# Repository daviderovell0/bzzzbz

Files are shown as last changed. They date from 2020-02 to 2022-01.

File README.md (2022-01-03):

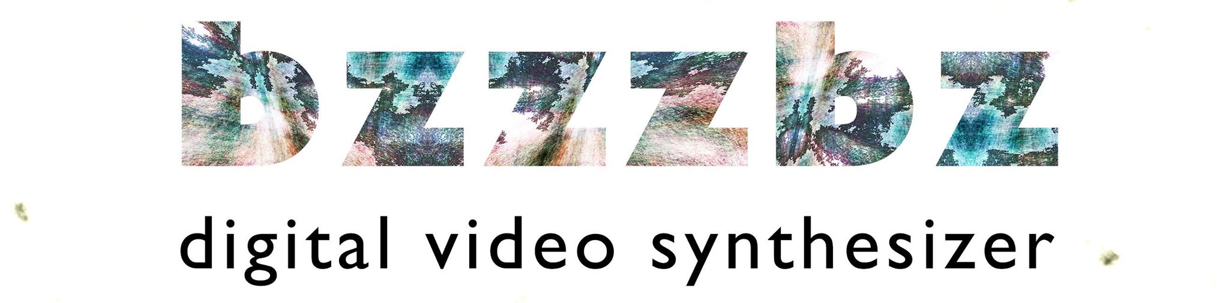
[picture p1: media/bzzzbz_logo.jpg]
bzzzbz Logo

**bzzzbz** is a video synthesizer that dynamically reacts to an audio input to create images and visuals that can be manipulated for integrated audio-visual performances.  <br>
This product is meant to be a simpler and cheaper alternative to commercial analog video synthesizers, still providing a flexible interface to enhance musical expression.

If you are a musician, a visual artist or are curious about the mesmerizing videos on the wall of your local techno club, build and use  **bzzzbz** to experiment and play with audio-reactive visuals! Among its main features, this open-source video synth gives you the live control of video parameters and the possibility of creating your own mappings and patterns for immersive audiovisual performances.
## Documentation
Visit our [wiki](https://github.com/daviderovell0/bzzzbz/wiki) for the full documentation. 
## Contributions
- Davide Rovelli (daviderovell0)
- Peter Nagy (deetrone)
- Marcell Illyes (marcellillyes)

This project was born at the University of Glasgow, School of Engineering. Credits to Dr.Bernd Porr, Dr. Nicholas Bailey and their Real Time Embedded Programming course.

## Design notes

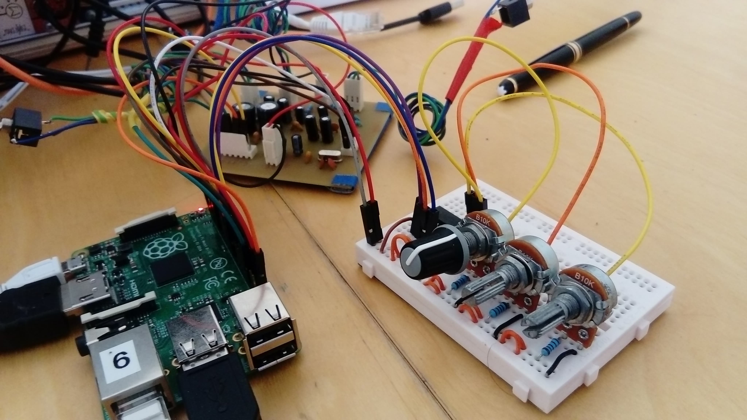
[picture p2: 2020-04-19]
media/hardware_prototype_full.jpg

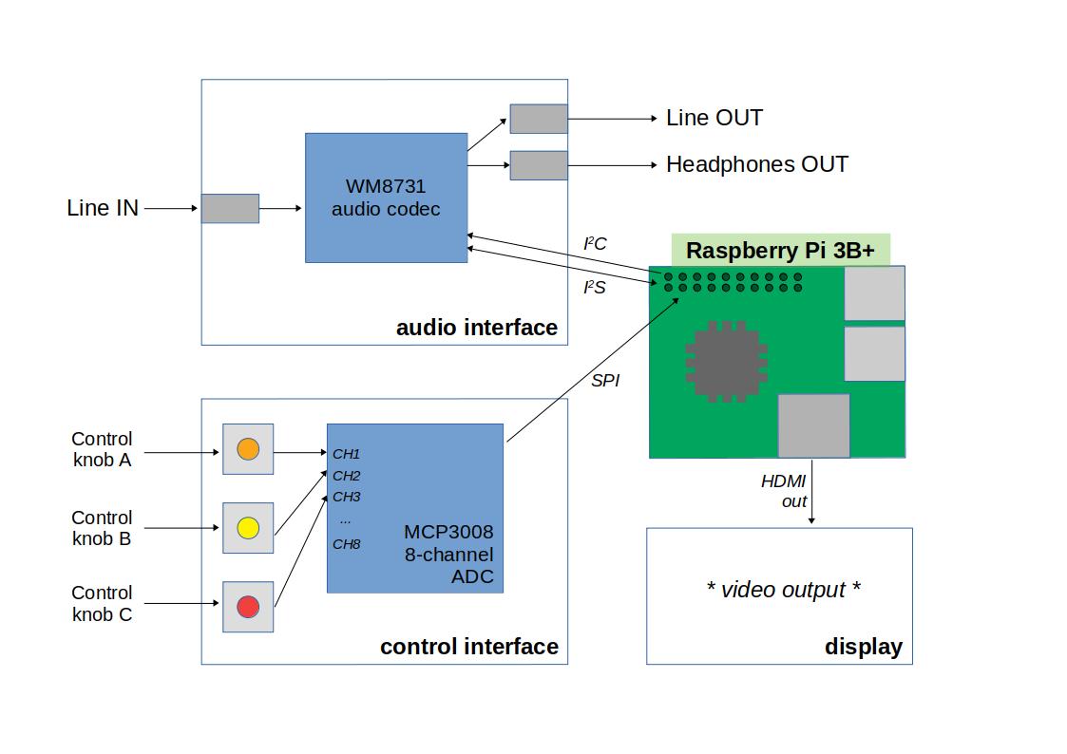
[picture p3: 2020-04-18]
media/hardware_diagram.jpg

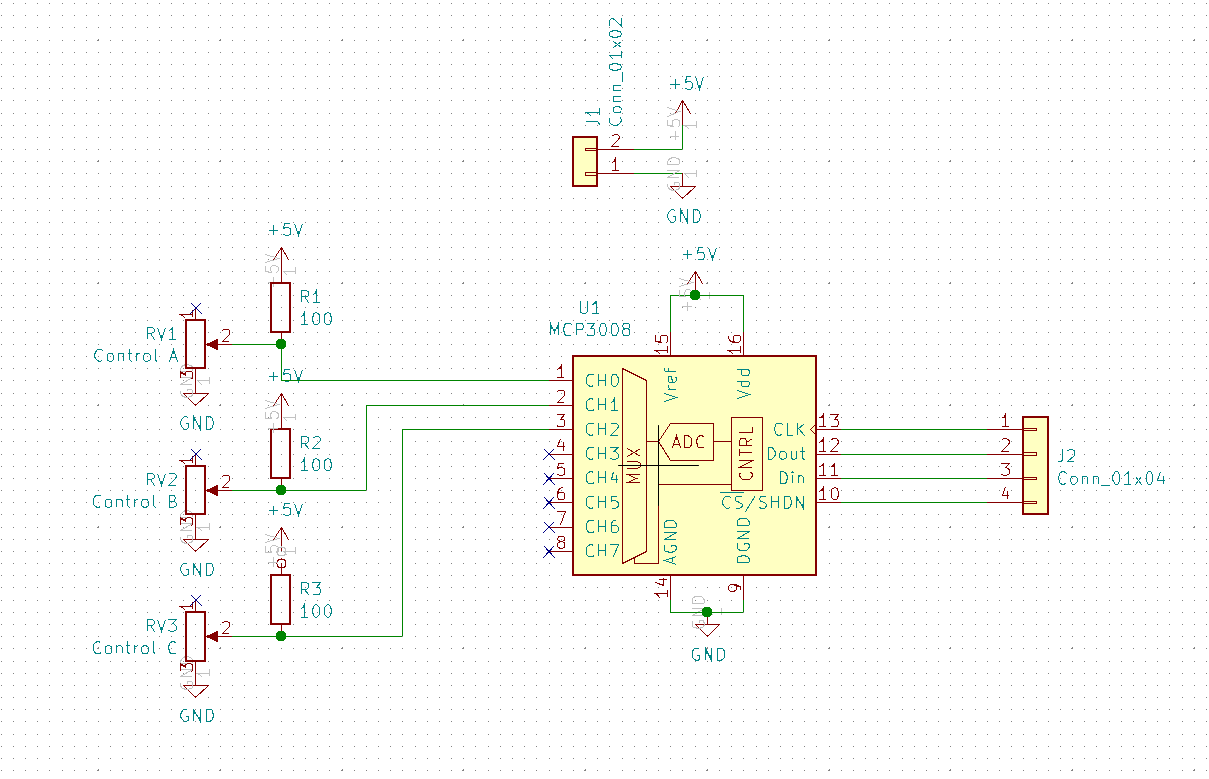
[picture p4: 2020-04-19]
media/mcp3008_breakout_schematic.png

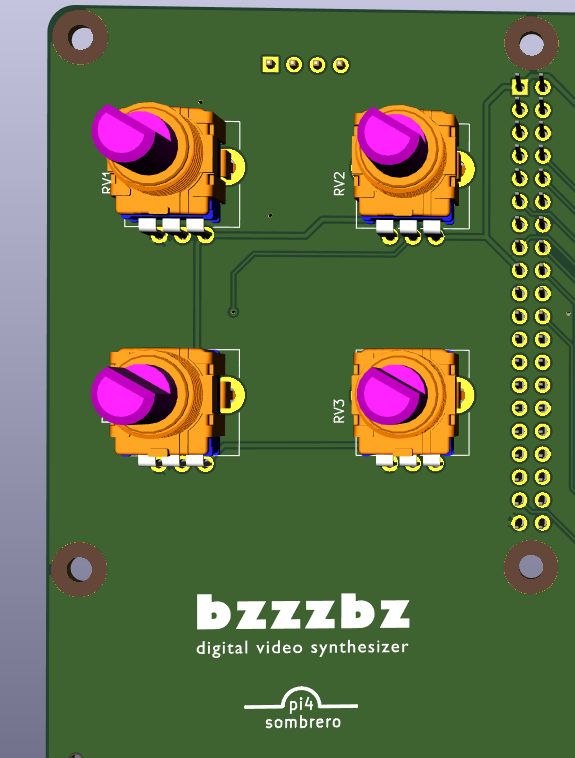
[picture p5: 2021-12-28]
hardware/3dmodels/pots_view.png

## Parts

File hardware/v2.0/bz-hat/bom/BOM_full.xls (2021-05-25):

BZZZBZ
References | Value | Mouser No / JLCPCB | Mfr. No | Manufacturer | Description | Order Qty. | Price (EUR) | Ext.: (EUR)
J1,J2,J3 | LineIN,LineOUT,Headphones | 490-SJ1-3533NG | SJ1-3533NG | CUI Devices | Phone Connectors Audio Jacks | 3 | 0.787 | 2.361
J4 |  | 485-1992 | 1992 | Adafruit | Adafruit Accessories GPIO Header for RaspberryPi A+/B+/Pi 2/Pi 3 - Tall 2x20 Female Header | 1 | 2.500 | 2.5
RV1, RV2, RV3, RV4 |  | 688-RK09L114001T | RK09L114001T | Alps Alpine | Potentiometers Flat 20mm 10k | 4 | 1.480 | 5.92
J5, J6 |  | 437-3508013100006101 | 350-80-131-00-006101 | Preci-dip | Headers & Wire Housings 31x1 female (only 20x1 + 4x1 needed) | 1 | 2.410 | 2.41
SW1, SW3, SW4, SW5 | BTN_1, BTN_2, BTN_3, BTN_f | 612-TL1100-6JBLK | TL1100F160Q6JBLK | E-Switch | Tactile Switches 50mA 12VDC SPST 12x12mm Blk Cap | 4 | 0.636 | 2.544
SW2 | BTN_big | 612-PB300STQ | PB300STQ | E-Switch | Pushbutton Switches Long Travel Pushbutton Switch 30mA 28VDC SPST 490+/- 150gf -40 C to 95 C | 1 | 1.410 | 1.41
U1, U3 | MCP3004 | 579-MCP3004-I/SL | MCP3004-I/SL | Microchip | Analog to Digital Converters - ADC 10-bit SPI 4 Chl IND TEMP, SOIC14 | 2 | 1.850 | 3.7
J6 |  | 437-3508013100006101 | 350-80-131-00-006101 | Preci-dip | Header for display: 2.54mm pitch, 20x1, male | 1 | 2.400 | 2.4
J6 | NHD-2.23-12832UCB3 | 763-NHD22312832UCW3 | NHD-2.23-12832UCW3 | Newhaven Display | OLED Displays & Accessories 2.23 Graphic OLED White | 1 | 23.430 | 23.43
U2 | WM8731 | / | WM8731SEDS/V | Cirrus Logic | Audio analog to digital converter - 24 bit headphone + line in + lineout | 1 | 3.62 | 3.62
C3, C4, C7, C8, C18, C20 | 1uF | JLCPCB parts | TAJA105K035RNJ | AVX | Tantalum capacitor SMT | 6 | 0.13 | 0.78
C9, C10, C11, C15, C19 | 10uF | JLCPCB parts | TAJA106K016RNJ | AVX | Tantalum capacitor SMT | 5 | 0.17 | 0.85
C5, C6 | 220uF | JLCPCB parts | VES221M1CTR-0607 | LELON | Almuninum capacitor SMT | 2 | 0.04 | 0.08
C1, C2 | 220pF | JLCPCB parts | CL10B221KB8NNNC | Samsung Electro-Mechanics | Ceramic capacitor SMT | 2 | 0.006 | 0.012
C13 | 0.1uF | JLCPCB parts | CL31B104KBCNNNC | Samsung Electro-Mechanics | Ceramic capacitor SMT | 1 | 0.02 | 0.02
C12, C14, C16, C17 | 0.1uF | JLCPCB parts | CC0603KRX7R9BB104 | Yageo | Ceramic capacitor SMT | 4 | 0.006 | 0.024
R3, R4 | 100 ohms | JLCPCB parts | 0805W8F1000T5E | Uniroyal Elec | Resistor SMT | 2 | 0.003 | 0.006
R7, R8, R9, R10 | 47k | JLCPCB parts | 0805W8F4702T5E | Uniroyal Elec | Resistor SMT | 4 | 0.004 | 0.016
R1, R2, R5, R6 | 5.6k | JLCPCB parts | 0805W8F5601T5E | Uniroyal Elec | Resistor SMT | 4 | 0.004 | 0.016
J4 | Raspberry_Pi_4 | / | / | Adafruit | 2 GB | 1 | 40 | 40
- | spacers for pi | 534-24426 | 24426 | Keystone Electronics | Spacers, 2.5x18, female (2x16 would be better) | 6 | 0.62 | 3.72
- | spacers for display (optional) | ? | ? | ? | Spacers, 2.5x10, female | 4 | 0.62 | 2.48
 |  |  |  |  |  |  | Total | 98.299

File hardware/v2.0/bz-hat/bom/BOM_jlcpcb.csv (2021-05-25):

Comment | Designator | Footprint | LCSC
220pF | C1,C2 | Capacitor_SMD:C_0603_1608Metric | C1603
0.1uF | C13 | Capacitor_SMD:C_1206_3216Metric | C24497
10uF | C9,C10,C11,C15,C19 | Capacitor_Tantalum_SMD:CP_EIA-3216-18_Kemet-A | C7171
0.1uF | C12,C14,C16,C17 | Capacitor_SMD:C_0603_1608Metric | C14663
220uF | C5,C6 | Capacitor_SMD:CP_Elec_6.3x7.7 | C127327
1uF | C3,C4,C7,C8,C18,C20 | Capacitor_Tantalum_SMD:CP_EIA-3216-18_Kemet-A | C7176
LineIN | J1 | custom:Jack_3.5mm_CUI_SJ1-3533NG_Horizontal
LineOUT | J2 | custom:Jack_3.5mm_CUI_SJ1-3533NG_Horizontal
Headphones | J3 | custom:Jack_3.5mm_CUI_SJ1-3533NG_Horizontal
Raspberry_Pi_4 | J4 | custom:PinHeader_2x20_P2.54mm_Vertical_RaspberryPI_HAT
CVs+CLK_connector | J5 | Connector_PinHeader_2.54mm:PinHeader_1x04_P2.54mm_Vertical
NHD-2.23-12832UCB3 | J6 | custom:Display_NHD-2.23-12832
5.6k | R1,R2,R5,R6 | Resistor_SMD:R_0805_2012Metric | C4382
100 | R3,R4 | Resistor_SMD:R_0805_2012Metric | C17408
47k | R7,R8,R9,R10 | Resistor_SMD:R_0805_2012Metric | C17713
10k | RV1,RV2,RV3,RV4 | Potentiometer_THT:Potentiometer_Alps_RK09L_Single_Vertical
BTN_f | SW1 | custom:SW_PUSH-12mm+3d
BTN_big | SW2 | custom:SW_PUSH_e-switch_PB300_SPST_12x12
BTN_1 | SW3 | custom:SW_PUSH-12mm+3d
BTN_2 | SW4 | custom:SW_PUSH-12mm+3d
BTN_3 | SW5 | custom:SW_PUSH-12mm+3d
MCP3004 | U1,U3 | Package_SO:SOIC-14_3.9x8.7mm_P1.27mm | C512186
WM8731 | U2 | custom:SSOP28-0.65-10.2X5.2MM | C323837

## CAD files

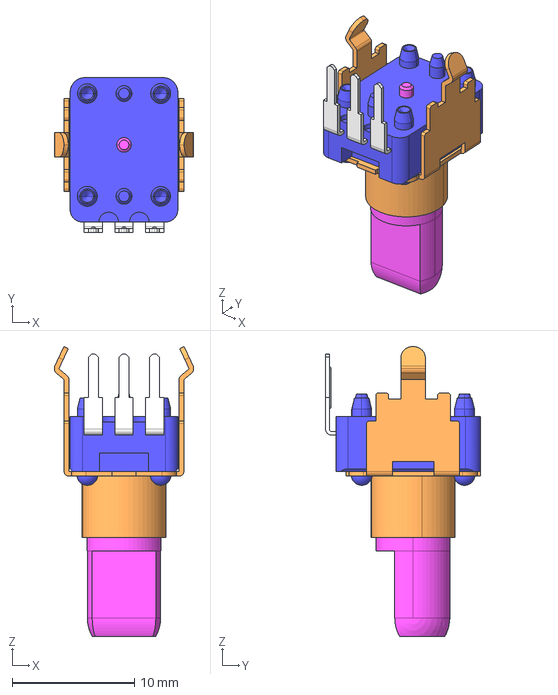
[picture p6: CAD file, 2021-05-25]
hardware/3dmodels/rk09d1130c3w.stp
11.4 x 12.7 x 23.7 mm

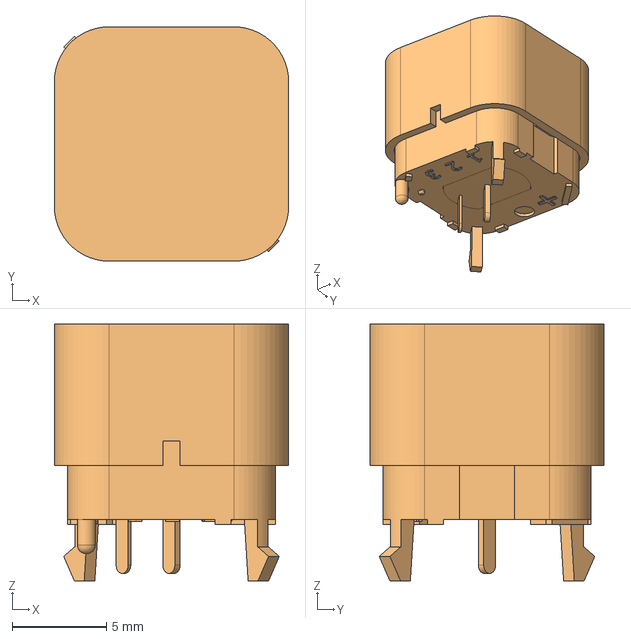
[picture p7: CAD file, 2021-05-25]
hardware/3dmodels/PB300STQ--3DModel-STEP-1.STEP
12.4 x 12.4 x 13.6 mm

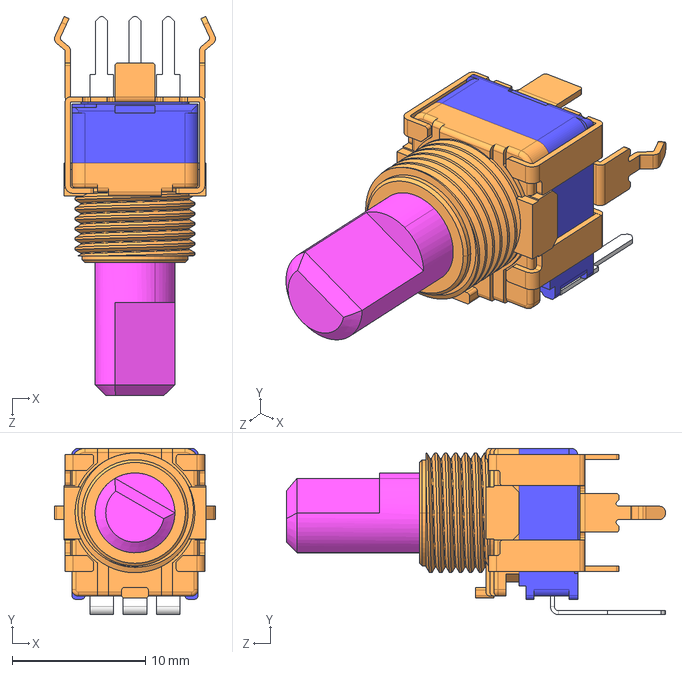
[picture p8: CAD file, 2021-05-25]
hardware/3dmodels/RK09L1140A5P.STEP
12.1 x 12.5 x 28.5 mm

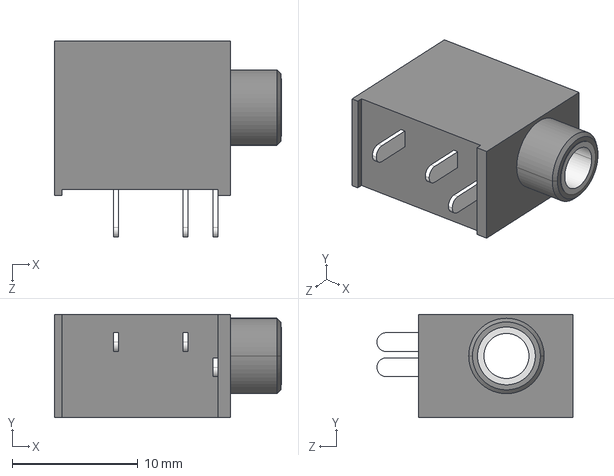
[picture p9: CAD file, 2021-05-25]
hardware/3dmodels/CUI_DEVICES_SJ1-3533NG.step
18.1 x 8.20 x 15.6 mm

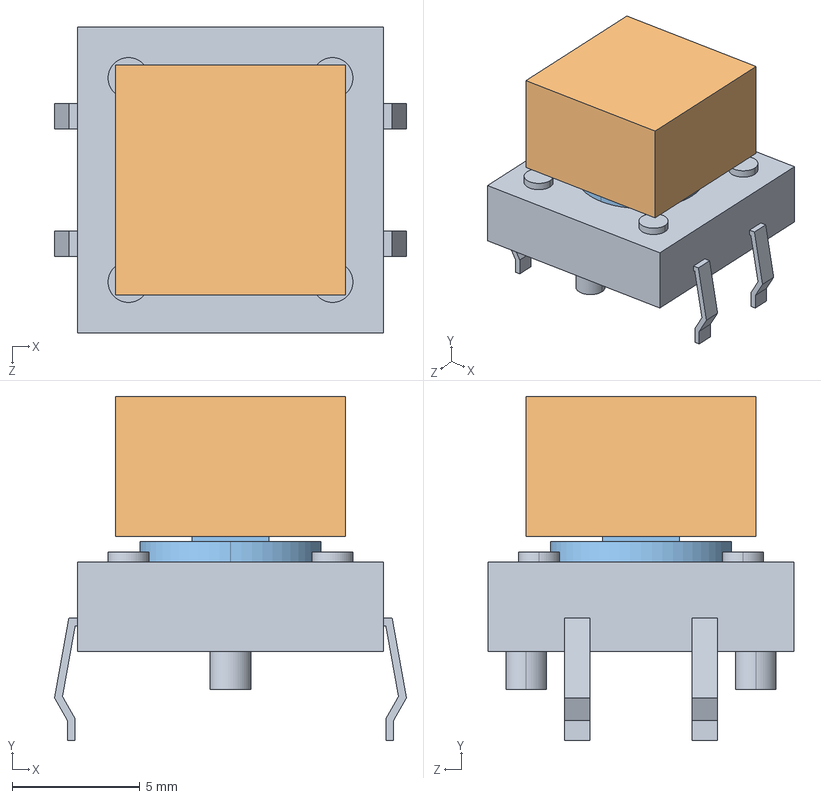
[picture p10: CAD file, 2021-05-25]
hardware/3dmodels/B3F-4050--3DModel-STEP-273799.STEP
13.8 x 13.5 x 12.0 mm
B3F_4050_BASE
B32_1200
B3F_4050_BUTTON

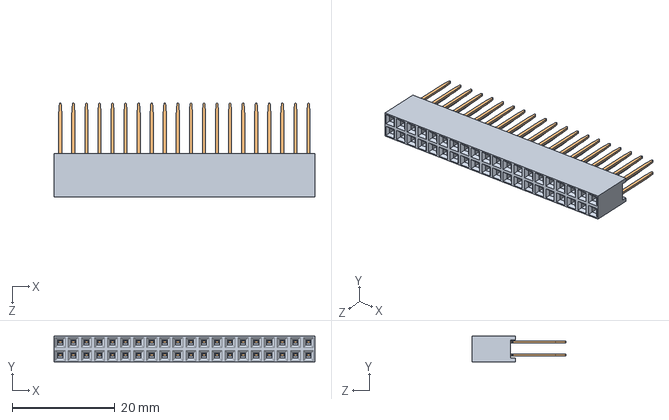
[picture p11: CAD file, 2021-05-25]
hardware/3dmodels/960240-6202-AR.STEP
50.8 x 5.00 x 18.3 mm
960240-6202-AR Body
960240-6202-AR Pin x 40

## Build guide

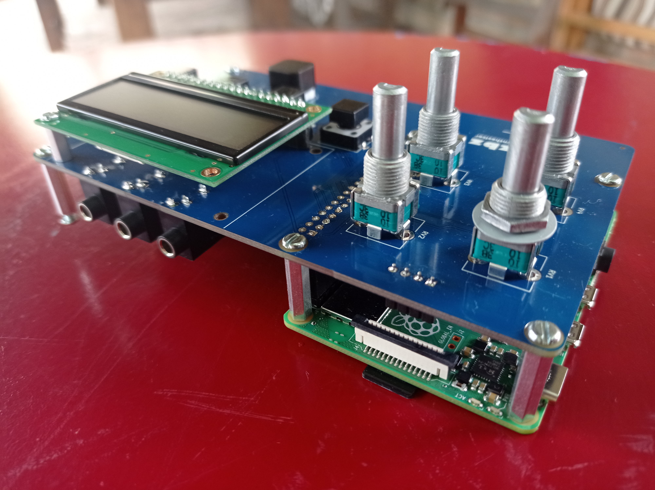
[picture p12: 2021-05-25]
media/board_v2_assembled_back.jpg

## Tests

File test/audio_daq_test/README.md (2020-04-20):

## Audio acquisition test

This folder contains a simple program that prints the samples coming from an audio port
of your device:
- For bzzzbz this would be the lineIN left channel of the stereo jack.
- For a laptop this is likely to be your build-in microphone.

It can be used to understand how the audio acquisition and processing works and also to 
test if the device receives audio data. Run:
```
cmake .
make
./audioin.o
```
If you see the samples varying accordingly to the input the audio is working.

### Plotting audio data
The *plot* folder contains a jupyter notebook that can be used to visualise audio data in the 
*samples* folder. The samples were recorded from **bzzzbz** line input. Files starting with *fft*
represent the frequency equivalent of the raw samples.

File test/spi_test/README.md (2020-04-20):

## SPI acquisition test

This folder contains a simple program that prints the samples coming from the control knobs
of **bzzzbz**.

It can be used to understand how the SPI clients manages acquisition and processing works and also to 
test if the device receives SPI data. Run:
```
cmake .
make
./spi_test.o
```
If you see the samples varying accordingly to the input the audio is working.

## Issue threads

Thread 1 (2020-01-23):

Sound processing design

daviderovell0, 2020-01-23:
We need to design specifications for the audio processing of bzzzbz video synth.

Currently ADC chip with jack input seems the most reasonable option.

deetrone, 2020-01-23:
E-mail Dr Porr to see if we can use external sound cards (hats)
Research available hats (important 192kHz, price, in/out?)

deetrone, 2020-01-24:
OG I2S specification:
https://web.archive.org/web/20080706121949/http://www.nxp.com/acrobat_download/various/I2SBUS.pdf

Pi as an oscilloscope (Kernel building stuff):
https://digibird1.wordpress.com/raspberry-pi-as-an-oscilloscope-10-msps/

Sticky thread on RPi forum re: I2S:
https://www.raspberrypi.org/forums/viewtopic.php?f=44&t=8496&start=575#p604231

deetrone, 2020-01-25:
I2S GPIO connections to TI PCM1808 ADC:

BCK/SCK - PCM-CLK-18 - pin8 on ADC (BCK)

WS/LRCLK/FS - PCM-FS 19 -  pin7 on ADC (LRCK)

SDIN - PCMDIN 20 - pin9 on ADC (DOUT)

+ clock, SCKI on ADC which is the "fast clock"

Closed 2020-04-02.

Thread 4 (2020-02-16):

Control surface / sensors design

daviderovell0, 2020-02-16:
We need to come up with a design for an expressive surface to control the video "synthesis" parameters.
We need to:
- choose the functions / actions we want to have
- choose sensors accordingly
- prototype them on breadboard
- PCB and surface/box design
- Assemble them together

Closed 2020-02-26.

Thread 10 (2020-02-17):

Breakout PCB

daviderovell0, 2020-02-17:
( #1 )
Check [datasheet](https://statics.cirrus.com/pubs/proDatasheet/WM8731_v4.9.pdf)
Check ONDA driver and make breakout

daviderovell0, 2020-03-04:
PCB submitted and manufactured, KiCAD files can be found in the *repo/hardware* folder

Closed 2020-03-04.

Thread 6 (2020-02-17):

Capabilities of OpenGL in the RaspberryPi

daviderovell0, 2020-02-17:
(#2)

How much processing power do we need for certain HQ graphics (such as fractals)?
Can the RaspberryPI support them?

Shall we consider generating video on a laptop and make the RaspberryPi send data only?

daviderovell0, 2020-02-19:
OpenGL ES (embedded system) 2.x

Closed 2020-02-26.

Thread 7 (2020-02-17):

Sensor types and prices

daviderovell0, 2020-02-17:
(#4)

Choose the expressive sensors, choose the ADCs (they MUST have already a kernel driver for raspbian).
Make sure that we have enough GPIO to interface with the ADCs and buttons.
Ensure we are under budget.

Closed 2020-02-19.

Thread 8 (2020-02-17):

Potentiometer GPIO sample program

daviderovell0, 2020-02-17:
( #4 )

Write a sample program that reads the input from the ADC connected to the potentiometer to start control off and have a reference for future work.

daviderovell0, 2020-02-17:
We have to use a third party library such as wiringPi or BCM2835

daviderovell0, 2020-04-02:
Implemented in Pull request: #29

Closed 2020-04-02.

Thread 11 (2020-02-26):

OpenGL video generation

daviderovell0, 2020-02-26:
Now that openGL is installed and running we need to get familiar with OpenGL functions and workflow in order to manipulate videos

daviderovell0, 2020-02-26:
- Broad OpenGL overview of main features
- Make a simple video prototype

daviderovell0, 2020-03-04:
This issue was migrated to #13 with more specuifications.

Closed 2020-03-04.

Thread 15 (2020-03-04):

Audio data stream

daviderovell0, 2020-03-04:
Get the audio data from the audio codec (WM8731).

plan:

- Solder PCB
- use ALSA or JACK to set the codec with the relevant options
- Capture the data in a cpp program

daviderovell0, 2020-03-28:
PR #27 plots audio data stream from the microphone of an Ubuntu laptop.

We have to replicate the process on the pi, although it might be impossible because of hardware faults in the soundcard.

daviderovell0, 2020-04-02:
Process successfully replicated on the PI, the samples were captured and saved on file at 48KHz. The current breakout board presents some issues on startup (the chip cannot be registered) and playback. However incoming audio can still be captured. Plots confirmed the validity of the audio data

Closed 2020-04-02.

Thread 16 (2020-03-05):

Box design and manufacture

daviderovell0, 2020-03-05:
Ideally we want to have a box or a sort of enclosure for controls input and outputs.

Design can be done in CAD (Solidworks)
Manufacture through 3D printing or laser cutting (?).

daviderovell0, 2020-03-23:
Manufacture suspended due to current COVID containment measures.

daviderovell0, 2020-09-01:
We back

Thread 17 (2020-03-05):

Final PCB design and mounting

daviderovell0, 2020-03-05:
PCB with control, audio input outputs and RasperryPi.
Steps:

- Final components design from prototype
- Order SMD components
- PCB design
- Assemble and test

daviderovell0, 2020-03-23:
Task currently suspended due to current COVID containment measures.

Closed 2020-09-01.

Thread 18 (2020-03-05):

Control surface data input

daviderovell0, 2020-03-05:
Further develop the simple potentiometer sample program (#8) to have an array of at least 4 potentiometers with data being read simultaneously (real time) from all 4.

Since the pots ADC uses SPI, the main idea is to write a loop that keeps switching SPI slave and reading each input in turn, fast enough to appear simultaneous. We might need to use /dev direct access programming instead of /sys library such as WiringPI to achieve higher speed.

daviderovell0, 2020-04-02:
Implemented in #29

Closed 2020-04-02.

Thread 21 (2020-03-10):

Slow response on the pi

daviderovell0, 2020-03-10:
Even using shaders (running on the pi GPU), a simple video shows some lags on the pi. The larger the window the more visible the lag.

daviderovell0, 2020-03-17:
Solved by installing OpenGL driver

Closed 2020-03-17.

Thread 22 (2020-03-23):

Headphone out unwanted high-pass filtered signal

daviderovell0, 2020-03-23:
The audio chip appears to be successfully bypassing the signal. The output is stable on the line out jack but not in the headphones out where the audio seems to miss the bass frequencies.

We need to figure out where this happens and fix it: it might be a circuit issue of the breakout board or a driver configuration.

daviderovell0, 2020-04-02:
It now appears to be on the LINEOUT instead

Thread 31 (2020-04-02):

RELEASE v1.0

daviderovell0, 2020-04-02:
Now that we have all the different sections working separately we need to put everything together in a main program. The most relevant points are:
- Mapping
- Thread sync
- Real time execution.

I suggest to do this in 2 separate merging: **video<->controls** and **audio<->FFT**. We can then proceed to merge the 2 into a single program and implement the mapping.
This will give us our first working prototype!

daviderovell0, 2020-04-19:
Code and examples up and working, need to refactor, link information to documentation and tidy up for the final release.

Closed 2020-04-20.

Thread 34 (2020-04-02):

Meaningful mapping

daviderovell0, 2020-04-02:
We need to find a way to meaningfully map audio and controls to video. For example a complex track with different instruments might map different frequencies to different video properties (i.e. object colors, size). However, this mapping might not make sense for a sine oscillator sweep for example, since the same "sound changing" would change different video properties.

We might be able to solve that with different types of mapping, giving the user the possibility to change according to its sound

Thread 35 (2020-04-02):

Control + video mapping

daviderovell0, 2020-04-02:
Refer to #31. Use the SPI potentiometer thread to update some test parameters in the video generation.
Test on laptop, then on PI.

daviderovell0, 2020-04-15:
Implemented in release_1.0 branch. Waiting for pull request to close

Closed 2020-04-18.

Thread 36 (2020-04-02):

Audio + FFT

daviderovell0, 2020-04-02:
Use jack thread to fill a buffer with incoming audio @ 48Khz, trigger an interrupt for the FFT processing.
Reasonable buffer sizes are 64 and 32 samples giving respectively 33 and 17 bins to parameterize the video.

Refer to release v1.0 -> #31

daviderovell0, 2020-04-07:
Implemented in releasev1.0 branch, waiting for the pull request to close

Closed 2020-04-18.

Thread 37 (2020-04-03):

FFT whole data representation

daviderovell0, 2020-04-03:
It is likely that we are going to have several "FFT frames" for a single video frame transition (at let's say 60fps). This means that if we simply read the FFT value at the time of the update, we lose the FFT values before that.

Instead, we could aggregate all the FFT values in between 2 video frames in some meaningful way (such as gradient / average), and use that value instead.

On the other hand, since the audio sampling and the FFT are very fast, the variation in the FFT frames in the video transition might be minimal, therefore making this issue irrelevant.

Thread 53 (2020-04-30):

CV and CLK in

deetrone, 2020-04-30:
Implement 4 (?) CV in and 1 clock in. With 4 knobs a single MCP3008 ADC might be enough but in the end might need two of them.

daviderovell0, 2020-09-02:
CV and some gates can exceed 10V up to 12V (?), so the MCP3008 is not enough as it has a max input of 7.6V. We have to use another ADC or decrease the voltage though some additional circuits

marcellillyes, 2020-09-02:
Yess I think we should first try out adding a simple op amp circuit to map
the eurorack range to MCP range.

daviderovell0 <notifications@github.com> ezt írta (időpont: 2020. szept.
2., Sze, 16:24):

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

marcellillyes, 2020-09-02:
Ill try model it in LTSpice

Marcell Illyés <300000persec@gmail.com> ezt írta (időpont: 2020. szept. 2.,
Sze, 16:33):

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

daviderovell0, 2020-09-02:
Sounds good. We can check also ADCs that take higher voltages so we can avoid making extra circuit

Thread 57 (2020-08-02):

v2.0 board

daviderovell0, 2020-08-02:
Design and assemble a single board for inputs, outputs and control to substitute the prototype breakout board.

## Features
- Upgrade to a Raspberry Pi 4
- linein, headphones and lineout (unchanged)
- CV and clock in
- Composite out
- Buttons: shader switch x2, on/off (?), shift button for extra funct.
- Knobs: 4/5 macro controls
- simple led screen (to display shaders name)

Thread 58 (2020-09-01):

Utility software features

daviderovell0, 2020-09-01:
Software needed to operate the hardware and to add functionalities that are not related to audio-video.

### Button functions
  - Switching shaders
  - Change DSP modes
### Display drive
We need to drive a display interactively to display either shaders name or the current information.
### Shader / code loading
Right now the shaders and the code is manually loaded. It could be nice to have some sort of interface to quickly load anything to bzzzbz.

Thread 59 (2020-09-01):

PCB design

daviderovell0, 2020-09-01:
Merge the control and audio breakout boards and expand the for the new features.

### New components

- [x] +1 ~~MCP3008~~ ADC for the CVs and CLK. see #53
- [x] Header for RPI4
- [x] Screen: **choose model**, components to drive it?
- [x] 4 buttons

### Requirements
- Make it as HAT for the Pi
- Conform to JLCPCB board design rules
- Components should be available from JLCPCB to exploit their SMT soldering

Closed 2022-01-03.

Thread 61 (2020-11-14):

Hardware components list

voidchi, 2020-11-14:
I would like to attempt this build, do you have a list of components required to assemble the prototype?

daviderovell0, 2020-11-15:
Hello, unfortunately there's not an actual components list for v1.0. However you can find all the components in the KiCad files (schematic + PCB) in the *hardware* folder in the project repo. You can follow the wiki for a guide on how to build the hardware and assemble the software.

voidchi, 2020-11-21:
Ace, I'll give it a shot!

Closed 2022-01-04.

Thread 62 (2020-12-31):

terminate called after throwing an instance of 'char const*'

henning, 2020-12-31:
Hi,

I dont get the program to work (on an Ubuntu 20.10):

```
$ ./src/bz
terminate called after throwing an instance of 'char const*'
Aborted (core dumped)
```

I never really learned C++, so before spending hours debugging, I ask if this is a known thing, or if there is a recommended Linux version where it should work, or if I better only try with a Raspberry device.

Thanks in advance! The project looks very promising and I would love to be able to use it! ;)

deetrone, 2021-01-02:
Hi,

The executable you are trying to run only works on Raspberry Pi with the control interface built. On a desktop device you can run some of the examples instead. There is more information in the user guide of our [wiki](https://github.com/daviderovell0/bzzzbz/wiki/User-Guide).

Great to hear your interest in the project :)

henning, 2021-01-14:
ok, thanks and sorry for not reading the docs properly - my bad :(

deetrone, 2021-01-18:
@henning No worries. We're glad you're giving our project a try even though it's in its infancy. Let us know if you have other issues or ideas. Admittedly the release is very early and rather unstable. We're hoping to get ahead with development and have a new version that is truly usable and fun so keep an eye on bzzzbz :)

Closed 2021-01-13.

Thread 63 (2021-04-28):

fatal error: kiss_fftr.h: No such File or directory

Cevahero, 2021-04-28:
Hi and thanks for the cool project!
Unfortunately I get this error message after `make` command.
Maybe I am just unexperienced (total noob haha), but I followed your instructions!
Attached a screenshot, maybe you can help. thanks a lot! :)

[Screenshot](https://ibb.co/gP82Vtc)

daviderovell0, 2021-05-05:
Hello,
It seems like your make doesn't find the _kiss_fftr.h_ file that is present in _src/kiss_fft/_, but I couldn't reproduce the error following the instructions.
Did you run `cmake .` before running `make`, from the repository root?

Great to know that you are trying the project out!

Closed 2022-01-03.

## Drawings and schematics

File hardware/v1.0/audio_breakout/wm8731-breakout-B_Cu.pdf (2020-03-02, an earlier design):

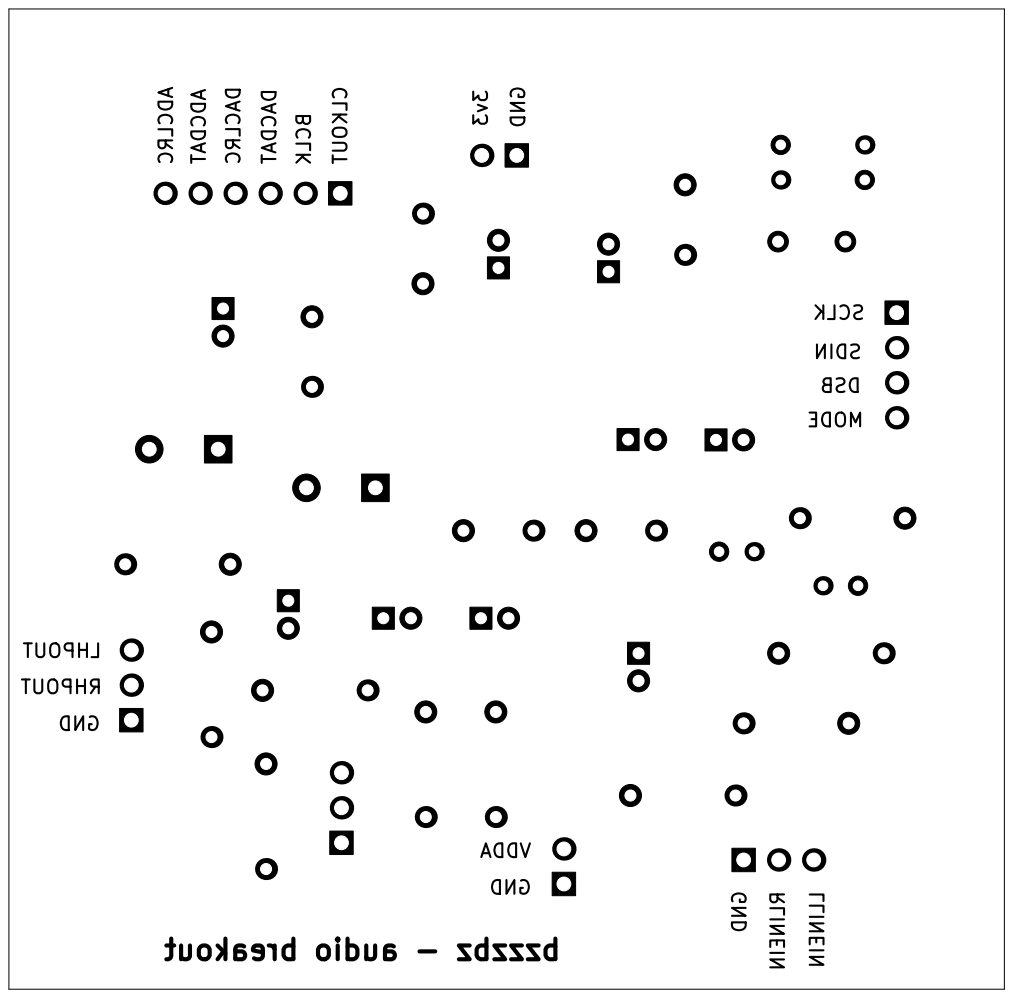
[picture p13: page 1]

LHPOUT RHPOUT GND ADCLRC ADCDAT DACLRC DACDAT BCLK CLKOUT 3v3 GND

SCLK GND RLINEIN LLINEIN

bzzzbz - audio breakout MODE DSB

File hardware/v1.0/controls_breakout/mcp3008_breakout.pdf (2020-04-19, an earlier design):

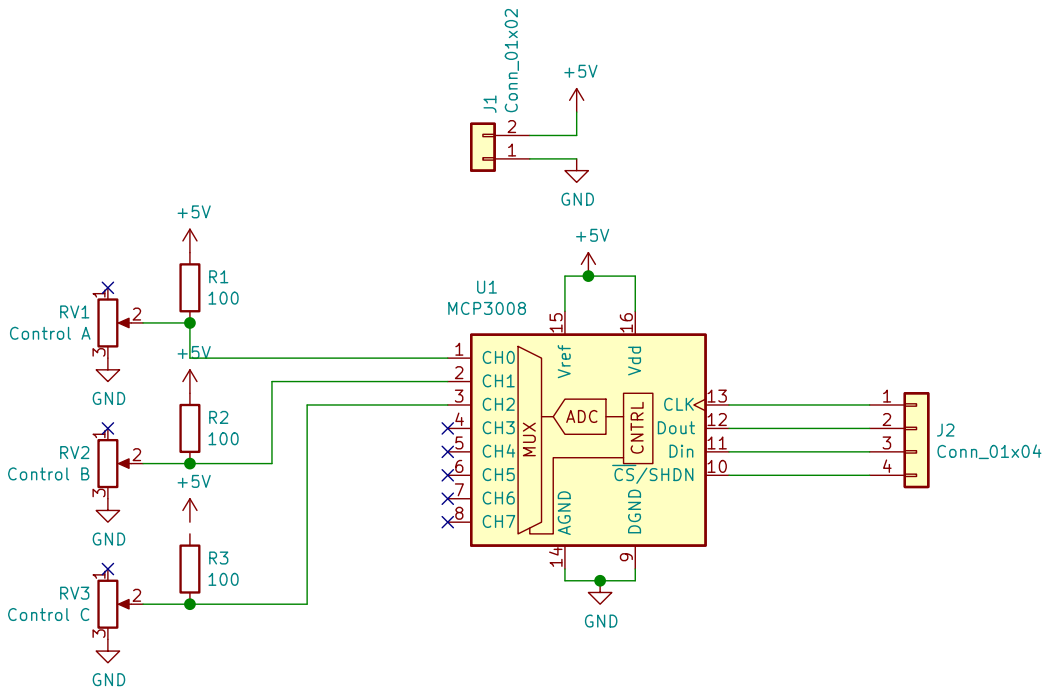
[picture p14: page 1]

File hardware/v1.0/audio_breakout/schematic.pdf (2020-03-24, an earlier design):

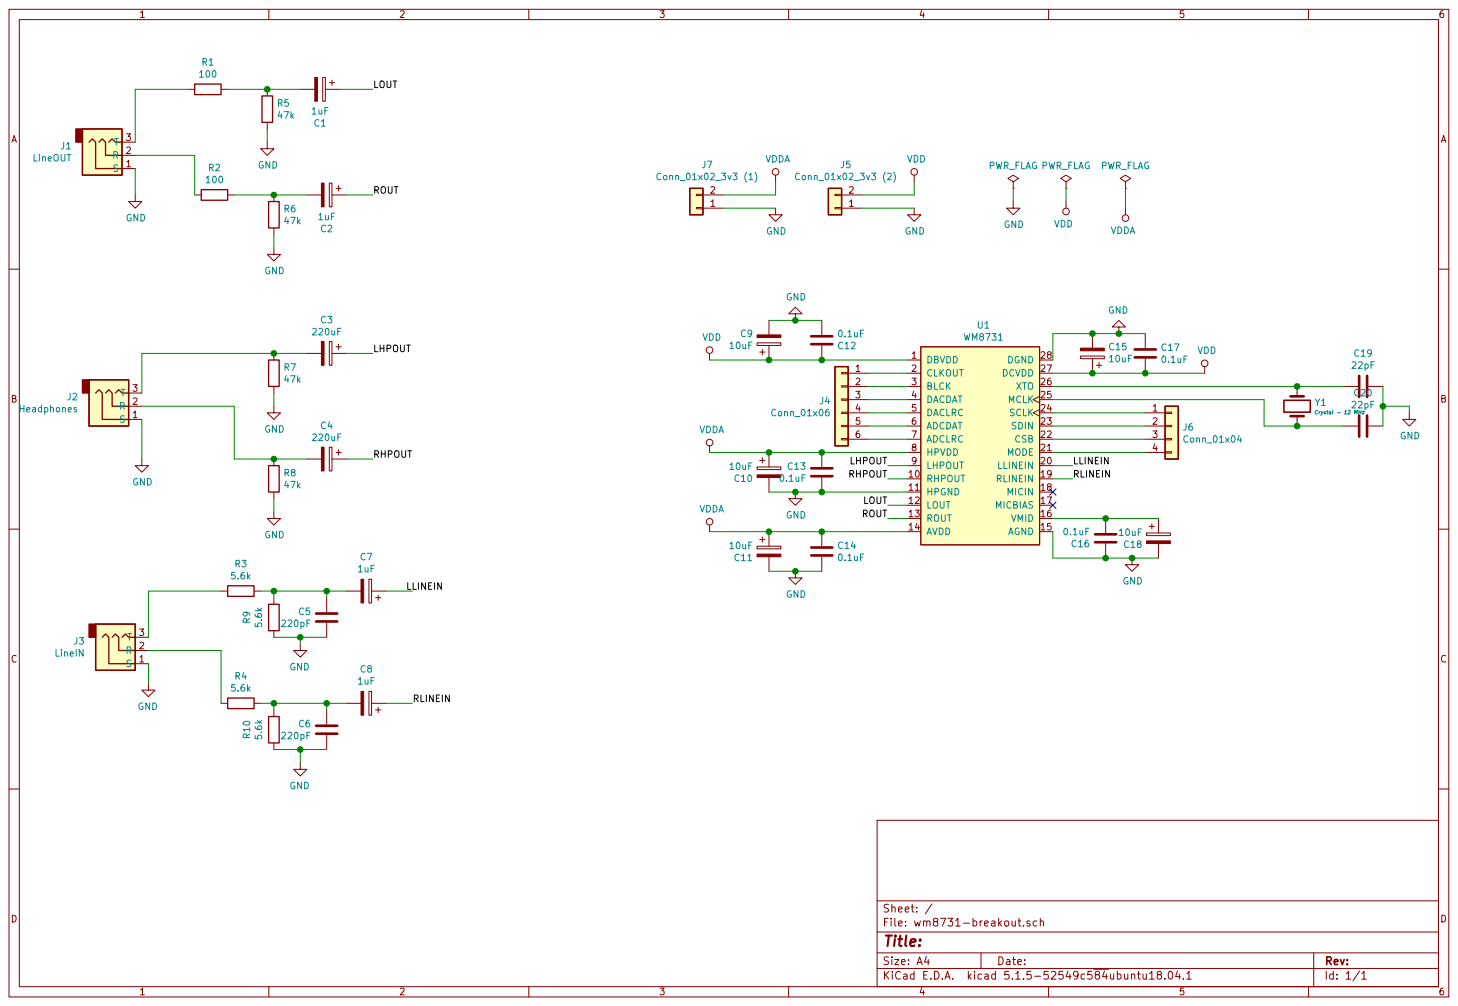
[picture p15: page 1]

Id: 1/1 Title: File: wm8731-breakout.sch Sheet: /

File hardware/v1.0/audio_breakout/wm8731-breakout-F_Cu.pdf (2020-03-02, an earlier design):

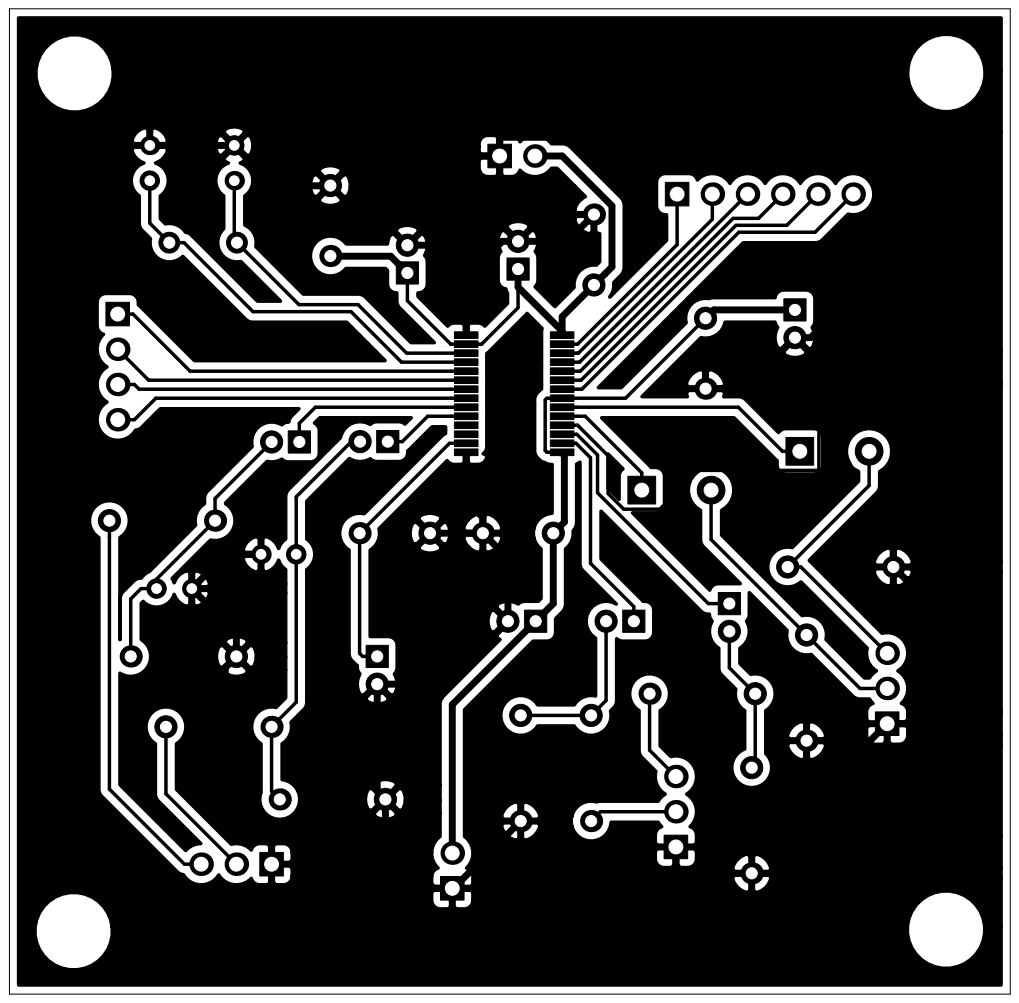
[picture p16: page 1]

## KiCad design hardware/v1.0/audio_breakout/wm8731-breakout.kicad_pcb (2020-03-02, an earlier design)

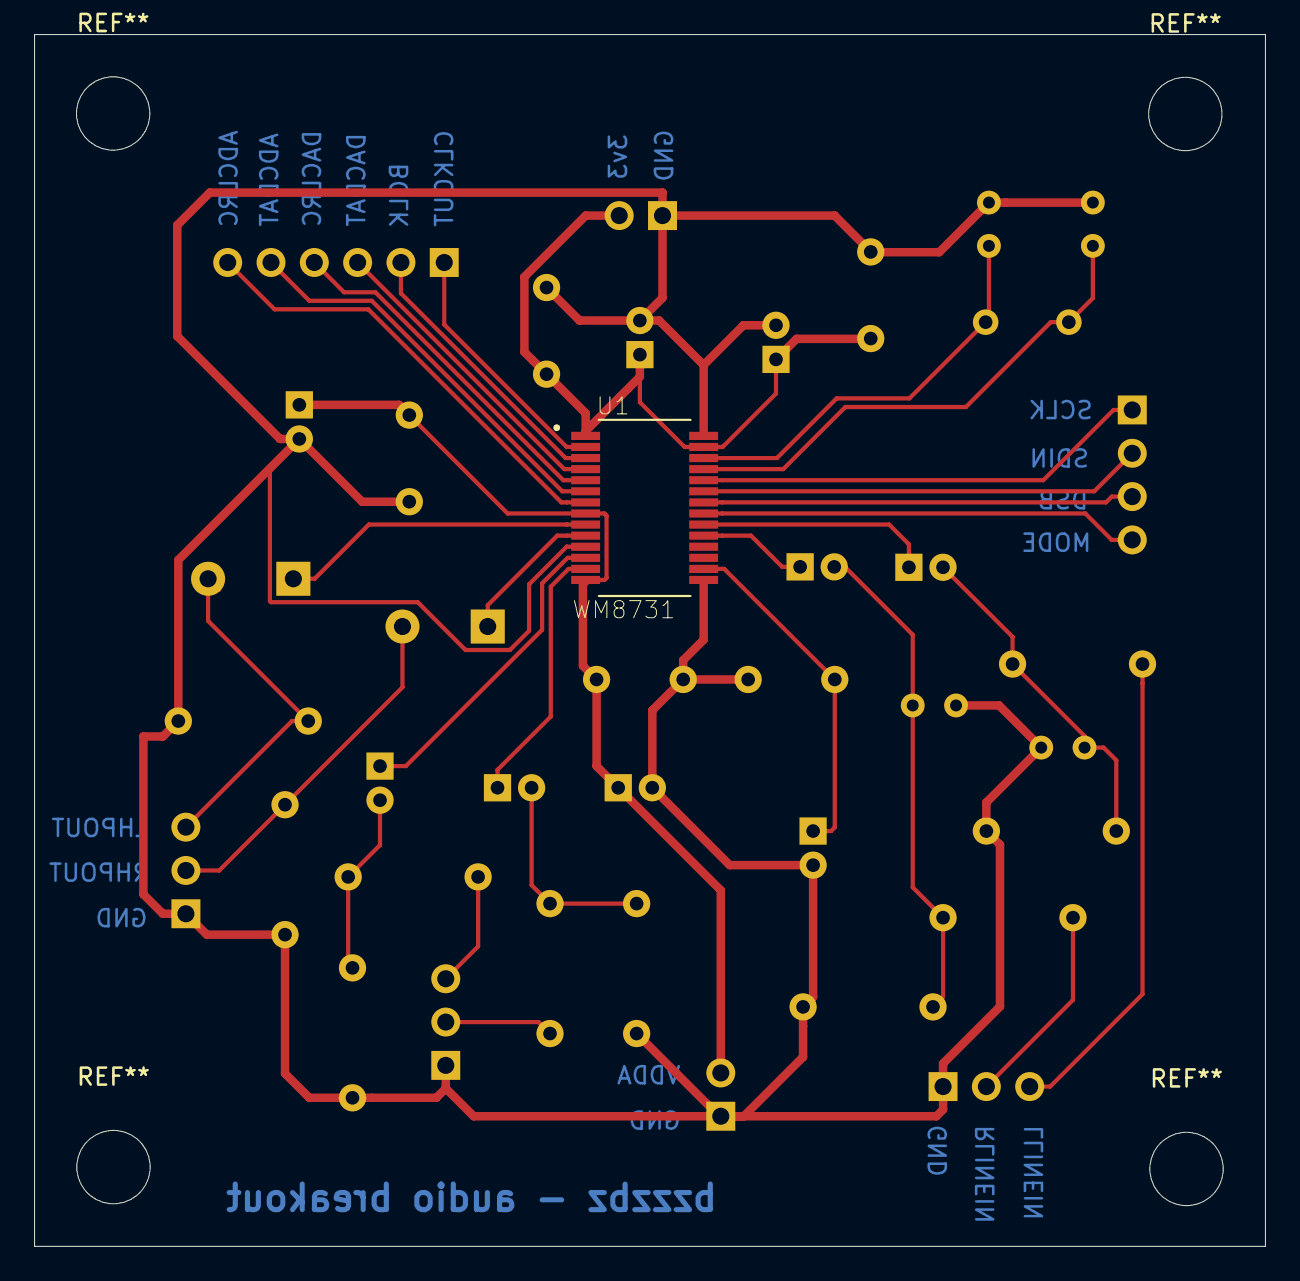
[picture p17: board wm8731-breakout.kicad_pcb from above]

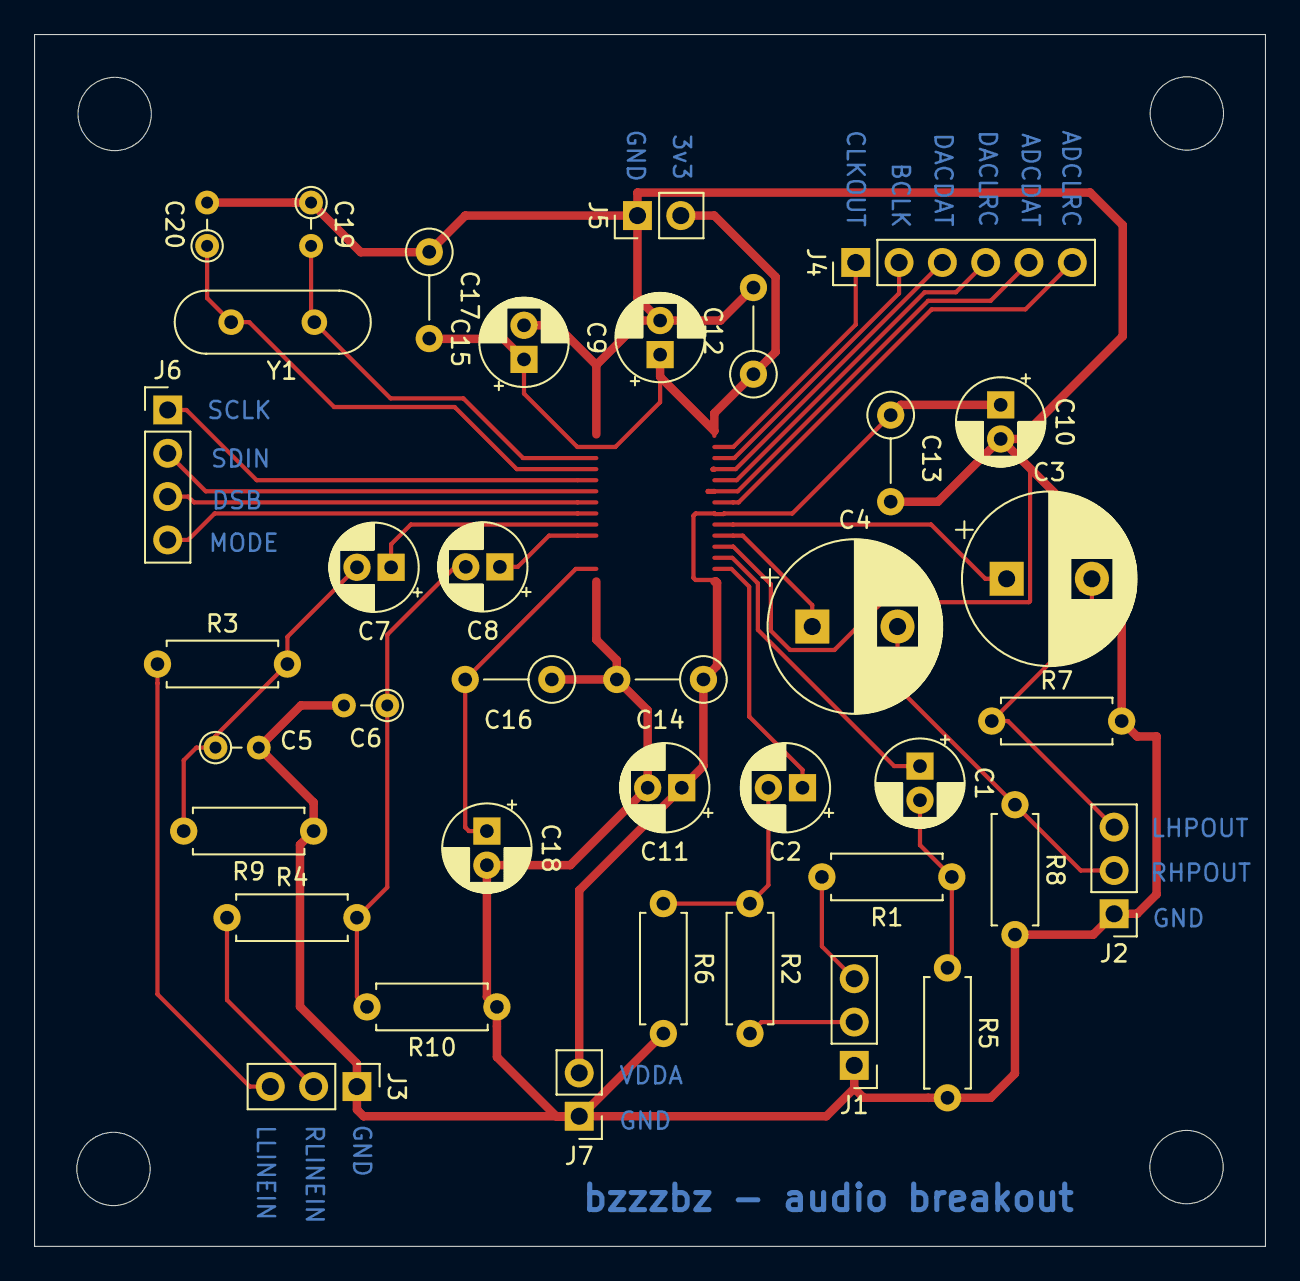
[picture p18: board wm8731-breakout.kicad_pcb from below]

Board: 2 copper layers, 72.2 x 71.1 mm, 39 parts (38 on the bottom side), 32 nets.

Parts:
C1, C2, C7, C8: 1uF; CP_Radial_D5.0mm_P2.00mm
C3, C4: 220uF; CP_Radial_D10.0mm_P5.00mm
C5, C6: 220pF; R_Axial_DIN0204_L3.6mm_D1.6mm_P2.54mm_Vertical
C9, C10, C11, C15, C18: 10uF; CP_Radial_D5.0mm_P2.00mm
C12, C13, C14, C16, C17: 0.1uF; R_Axial_DIN0207_L6.3mm_D2.5mm_P5.08mm_Vertical
C19, C20: 22pF; R_Axial_DIN0204_L3.6mm_D1.6mm_P2.54mm_Vertical
J1: LineOUT; PinHeader_1x03_P2.54mm_Vertical
J2: Headphones; PinHeader_1x03_P2.54mm_Vertical
J3: LineIN; PinHeader_1x03_P2.54mm_Vertical
J4: Conn_01x06; PinHeader_1x06_P2.54mm_Vertical
J5: Conn_01x02_3v3 (2); PinHeader_1x02_P2.54mm_Vertical
J6: Conn_01x04; PinHeader_1x04_P2.54mm_Vertical
J7: Conn_01x02_3v3 (1); PinHeader_1x02_P2.54mm_Vertical
R1, R2: 100; R_Axial_DIN0207_L6.3mm_D2.5mm_P7.62mm_Horizontal
R3, R4, R9, R10: 5.6k; R_Axial_DIN0207_L6.3mm_D2.5mm_P7.62mm_Horizontal
R5, R6, R7, R8: 47k; R_Axial_DIN0207_L6.3mm_D2.5mm_P7.62mm_Horizontal
U1: WM8731; SOP65P777X199-28N
Y1: Crystal - 12 MHz; Crystal_2pins_L11.5_P4.88_(9B-12.000MAAJ-B)

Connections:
/LHPOUT: C3.1, U1.9
/LLINEIN: C7.1, U1.20
/LOUT: C1.1, U1.12
/RHPOUT: C4.1, U1.10
/RLINEIN: C8.1, U1.19
/ROUT: C2.1, U1.13
GND: C5.2, C6.2, C9.2, C10.2, C11.2, C12.2, C13.2, C14.2, C15.2, C16.1, C17.1, C18.2, C19.1, C20.2, J1.1, J2.1, J3.1, J5.1, J7.1, R5.2, R6.2, R7.2, R8.2, R9.1, R10.1, U1.11, U1.15, U1.28
unnamed: C1.2, R1.1, R5.1
unnamed: C2.2, R2.1, R6.1
unnamed: C3.2, J2.3, R7.1
unnamed: C4.2, J2.2, R8.1
unnamed: C5.1, C7.2, R3.2, R9.2
unnamed: C6.1, C8.2, R4.2, R10.2
unnamed: C16.2, C18.1, U1.16
unnamed: C19.2, U1.26, Y1.1
unnamed: C20.1, U1.25, Y1.2
unnamed: J1.2, R2.2
unnamed: J1.3, R1.2
unnamed: J3.2, R4.1
unnamed: J3.3, R3.1
unnamed: J4.1, U1.2
unnamed: J4.2, U1.3
unnamed: J4.3, U1.4
unnamed: J4.4, U1.5
unnamed: J4.5, U1.6
unnamed: J4.6, U1.7
unnamed: J6.1, U1.24
unnamed: J6.2, U1.23
unnamed: J6.3, U1.22
unnamed: J6.4, U1.21
VDD: C9.1, C12.1, C15.1, C17.2, J5.2, U1.1, U1.27
VDDA: C10.1, C11.1, C13.1, C14.1, J7.2, U1.8, U1.14

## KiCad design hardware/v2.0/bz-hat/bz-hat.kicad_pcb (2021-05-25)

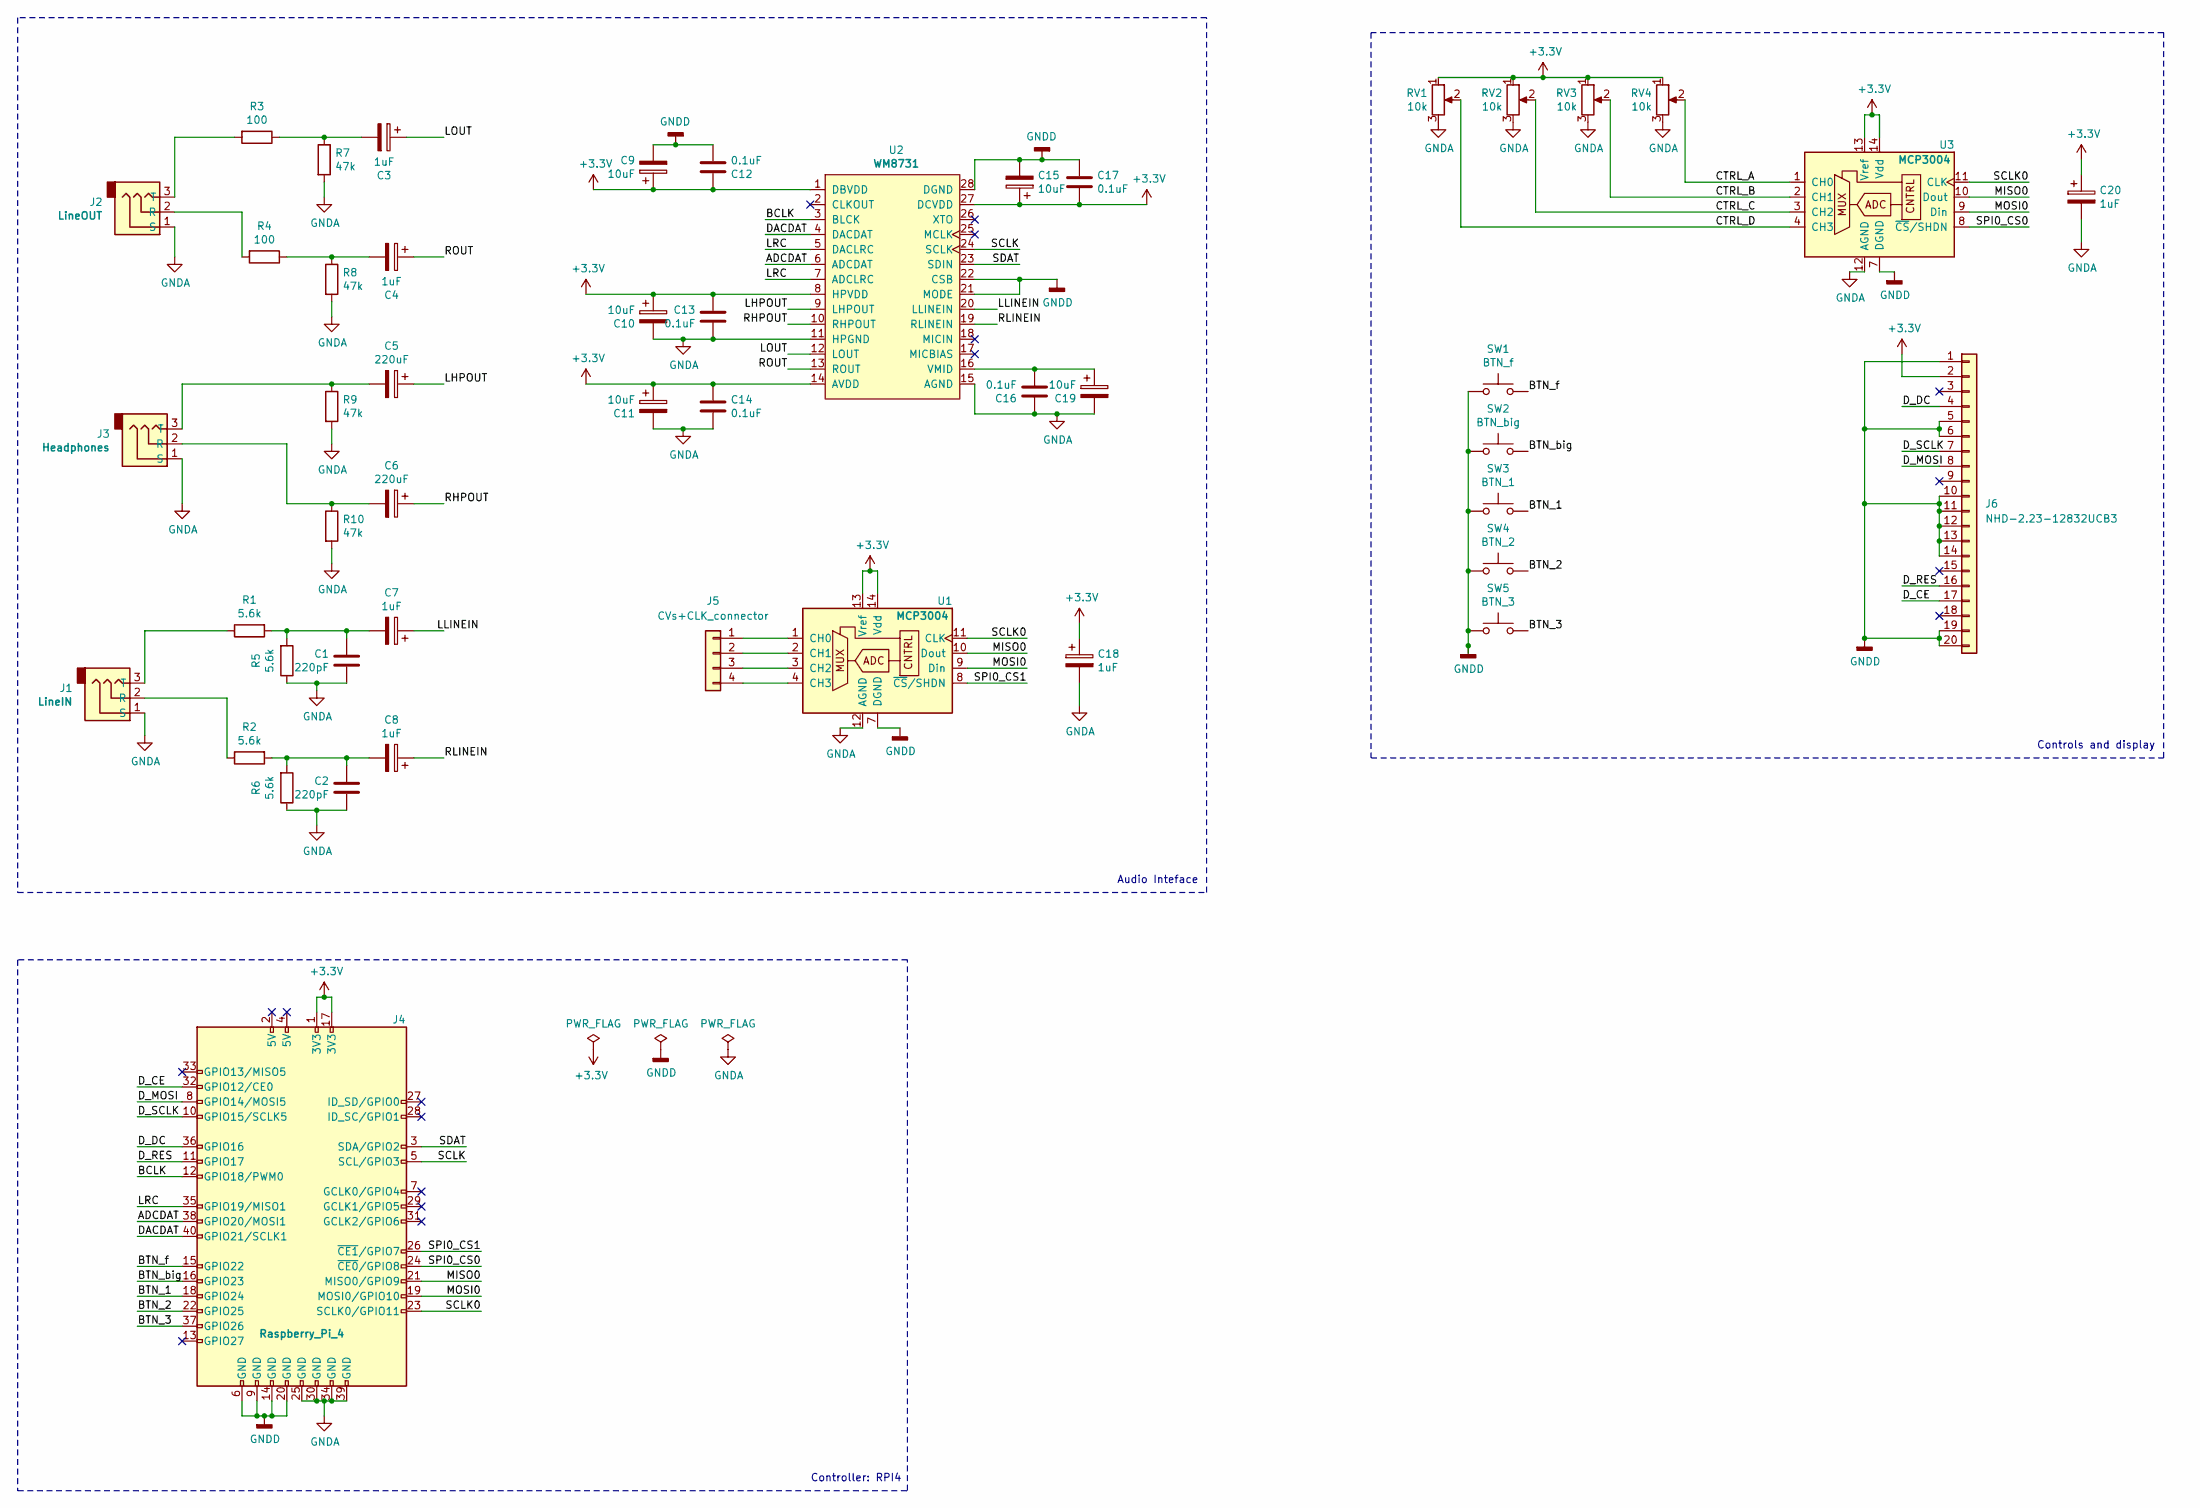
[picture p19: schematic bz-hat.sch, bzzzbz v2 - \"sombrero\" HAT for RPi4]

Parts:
C1, C2: 220pF; C_0603_1608Metric; Manufacturer part # CL10B221KB8NNNC; LCSC C1603
C3, C4, C7, C8, C18, C20: 1uF; CP_EIA-3216-18_Kemet-A; Manufacturer part # TAJA105K035RNJ; LCSC C7176
C5, C6: 220uF; CP_Elec_6.3x7.7; Manufacturer part # VES221M1CTR-0607; LCSC C127327
C9, C10, C11, C15, C19: 10uF; CP_EIA-3216-18_Kemet-A; Manufacturer part # TAJA106K016RNJ; LCSC C7171
C12, C14, C16, C17: 0.1uF; C_0603_1608Metric; Manufacturer part # CC0603KRX7R9BB104; LCSC C14663
C13: 0.1uF; C_1206_3216Metric; Manufacturer part # CL31B104KBCNNNC; LCSC C24497
J1: LineIN; Jack_3.5mm_CUI_SJ1-3533NG_Horizontal; Manufacturer part # SJ1-3533NG
J2: LineOUT; Jack_3.5mm_CUI_SJ1-3533NG_Horizontal; Manufacturer part # SJ1-3533NG
J3: Headphones; Jack_3.5mm_CUI_SJ1-3533NG_Horizontal; Manufacturer part # SJ1-3533NG
J4: Raspberry_Pi_4; PinHeader_2x20_P2.54mm_Vertical_RaspberryPI_HAT
J5: CVs+CLK_connector; PinHeader_1x04_P2.54mm_Vertical; Manufacturer part # 801-87-004-10-001101
J6: NHD-2.23-12832UCB3; Display_NHD-2.23-12832; Manufacturer part # NHD-2.23-12832UCB3
R1, R2, R5, R6: 5.6k; R_0805_2012Metric; Manufacturer part # 0805W8F5601T5E; LCSC C4382
R3, R4: 100; R_0805_2012Metric; Manufacturer part # 0805W8F1000T5E; LCSC C17408
R7, R8, R9, R10: 47k; R_0805_2012Metric; Manufacturer part # 0805W8F4702T5E; LCSC C17713
RV1, RV2, RV3, RV4: 10k; Potentiometer_Alps_RK09L_Single_Vertical; Manufacturer part # RK09L114001T
SW1: BTN_f; SW_PUSH-12mm+3d; Manufacturer part # TL1100F160Q6JBLK
SW2: BTN_big; SW_PUSH_e-switch_PB300_SPST_12x12; Manufacturer part # PB300STQ
SW3: BTN_1; SW_PUSH-12mm+3d; Manufacturer part # TL1100F160Q6JBLK
SW4: BTN_2; SW_PUSH-12mm+3d; Manufacturer part # TL1100F160Q6JBLK
SW5: BTN_3; SW_PUSH-12mm+3d; Manufacturer part # TL1100F160Q6JBLK
U1, U3: MCP3004; SOIC-14_3.9x8.7mm_P1.27mm; Manufacturer part # MCP3004-I/SL
U2: WM8731; SSOP28-0.65-10.2X5.2MM; Manufacturer part # WM8731SEDS/V

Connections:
+3V3: C9.1, C10.1, C11.1, C12.1, C13.1, C14.1, C15.1, C17.2, C18.1, C20.1, J4.1 (3V3), J4.17 (3V3), J6.2, RV1.1, RV2.1, RV3.1, RV4.1, U1.13 (Vref), U1.14 (Vdd), U2.1 (DBVDD), U2.8 (HPVDD), U2.14 (AVDD), U2.27 (DCVDD), U3.13 (Vref), U3.14 (Vdd)
/ADCDAT: J4.38 (GPIO20/MOSI1), U2.6 (ADCDAT)
/BCLK: J4.12 (GPIO18/PWM0), U2.3 (BLCK)
/BTN_1: J4.18 (GPIO24), SW3.2
/BTN_2: J4.22 (GPIO25), SW4.2
/BTN_3: J4.37 (GPIO26), SW5.2
/BTN_big: J4.16 (GPIO23), SW2.2
/BTN_f: J4.15 (GPIO22), SW1.2
/CTRL_A: RV4.2, U3.1 (CH0)
/CTRL_B: RV3.2, U3.2 (CH1)
/CTRL_C: RV2.2, U3.3 (CH2)
/CTRL_D: RV1.2, U3.4 (CH3)
/DACDAT: J4.40 (GPIO21/SCLK1), U2.4 (DACDAT)
/D_CE: J4.32 (GPIO12/CE0), J6.17
/D_DC: J4.36 (GPIO16), J6.4
/D_MOSI: J4.8 (GPIO14/MOSI5), J6.8
/D_RES: J4.11 (GPIO17), J6.16
/D_SCLK: J4.10 (GPIO15/SCLK5), J6.7
/LHPOUT: C5.1, U2.9 (LHPOUT)
/LLINEIN: C7.1, U2.20 (LLINEIN)
/LOUT: C3.1, U2.12 (LOUT)
/LRC: J4.35 (GPIO19/MISO1), U2.5 (DACLRC), U2.7 (ADCLRC)
/MISO0: J4.21 (MISO0/GPIO9), U1.10 (Dout), U3.10 (Dout)
/MOSI0: J4.19 (MOSI0/GPIO10), U1.9 (Din), U3.9 (Din)
/RHPOUT: C6.1, U2.10 (RHPOUT)
/RLINEIN: C8.1, U2.19 (RLINEIN)
/ROUT: C4.1, U2.13 (ROUT)
/SCLK: J4.5 (SCL/GPIO3), U2.24 (SCLK)
/SCLK0: J4.23 (SCLK0/GPIO11), U1.11 (CLK), U3.11 (CLK)
/SDAT: J4.3 (SDA/GPIO2), U2.23 (SDIN)
/SPI0_CS0: J4.24 (~CE0~/GPIO8), U3.8 (~CS~/SHDN)
/SPI0_CS1: J4.26 (~CE1~/GPIO7), U1.8 (~CS~/SHDN)
GNDA: C1.2, C2.2, C10.2, C11.2, C13.2, C14.2, C16.1, C18.2, C19.2, C20.2, J1.1 (S), J2.1 (S), J3.1 (S), J4.25 (GND), J4.30 (GND), J4.34 (GND), J4.39 (GND), R5.1, R6.1, R7.2, R8.2, R9.2, R10.2, RV1.3, RV2.3, RV3.3, RV4.3, U1.12 (AGND), U2.11 (HPGND), U2.15 (AGND), U3.12 (AGND)
GNDD: C9.2, C12.2, C15.2, C17.1, J4.6 (GND), J4.9 (GND), J4.14 (GND), J4.20 (GND), J6.1, J6.5, J6.6, J6.10, J6.11, J6.12, J6.13, J6.14, J6.19, J6.20, SW1.1, SW2.1, SW3.1, SW4.1, SW5.1, U1.7 (DGND), U2.21 (MODE), U2.22 (CSB), U2.28 (DGND), U3.7 (DGND)
unnamed: C1.1, C7.2, R1.2, R5.2
unnamed: C2.1, C8.2, R2.2, R6.2
unnamed: C3.2, R3.1, R7.1
unnamed: C4.2, R4.1, R8.1
unnamed: C5.2, J3.3 (T), R9.1
unnamed: C6.2, J3.2 (R), R10.1
unnamed: C16.2, C19.1, U2.16 (VMID)
unnamed: J1.2 (R), R2.1
unnamed: J1.3 (T), R1.1
unnamed: J2.2 (R), R4.2
unnamed: J2.3 (T), R3.2
unnamed: J5.1, U1.1 (CH0)
unnamed: J5.2, U1.2 (CH1)
unnamed: J5.3, U1.3 (CH2)
unnamed: J5.4, U1.4 (CH3)

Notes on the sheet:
Audio Inteface
Controls and display
Controller: RPI4

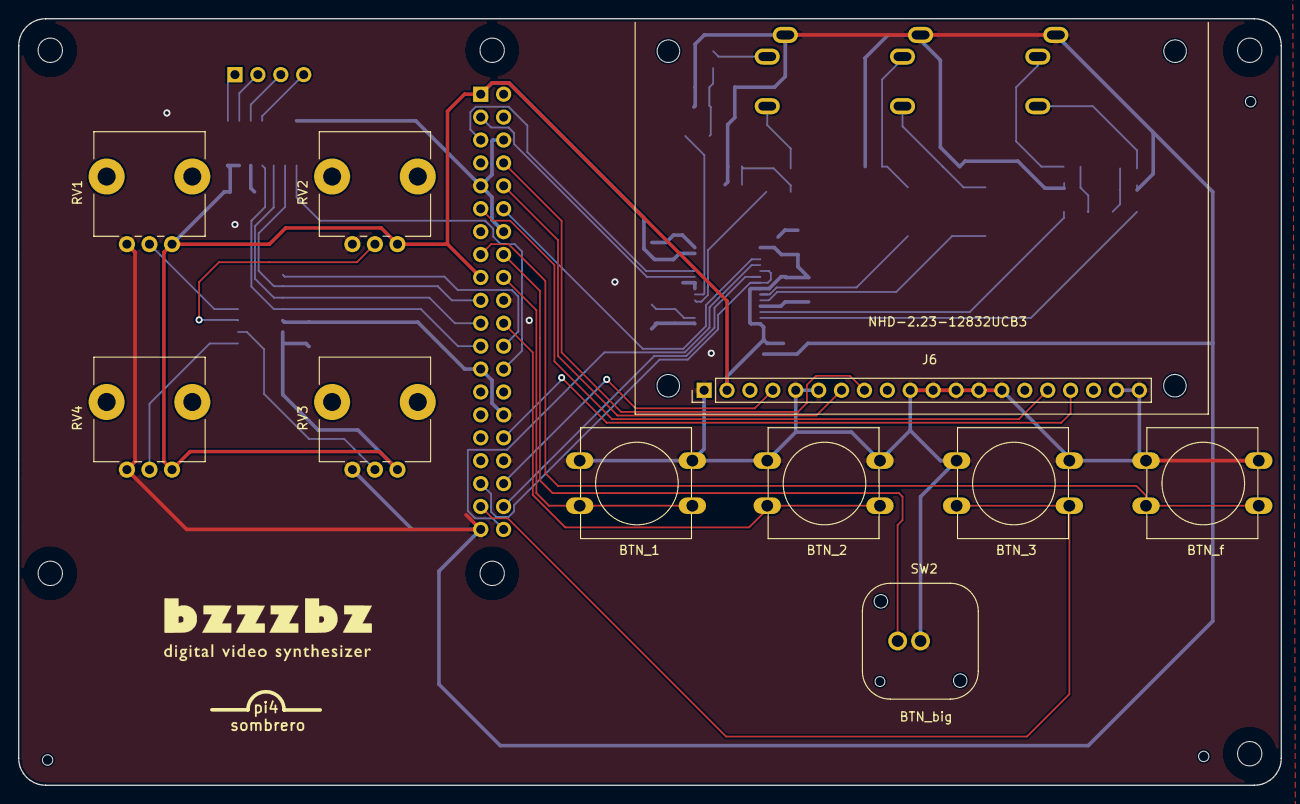
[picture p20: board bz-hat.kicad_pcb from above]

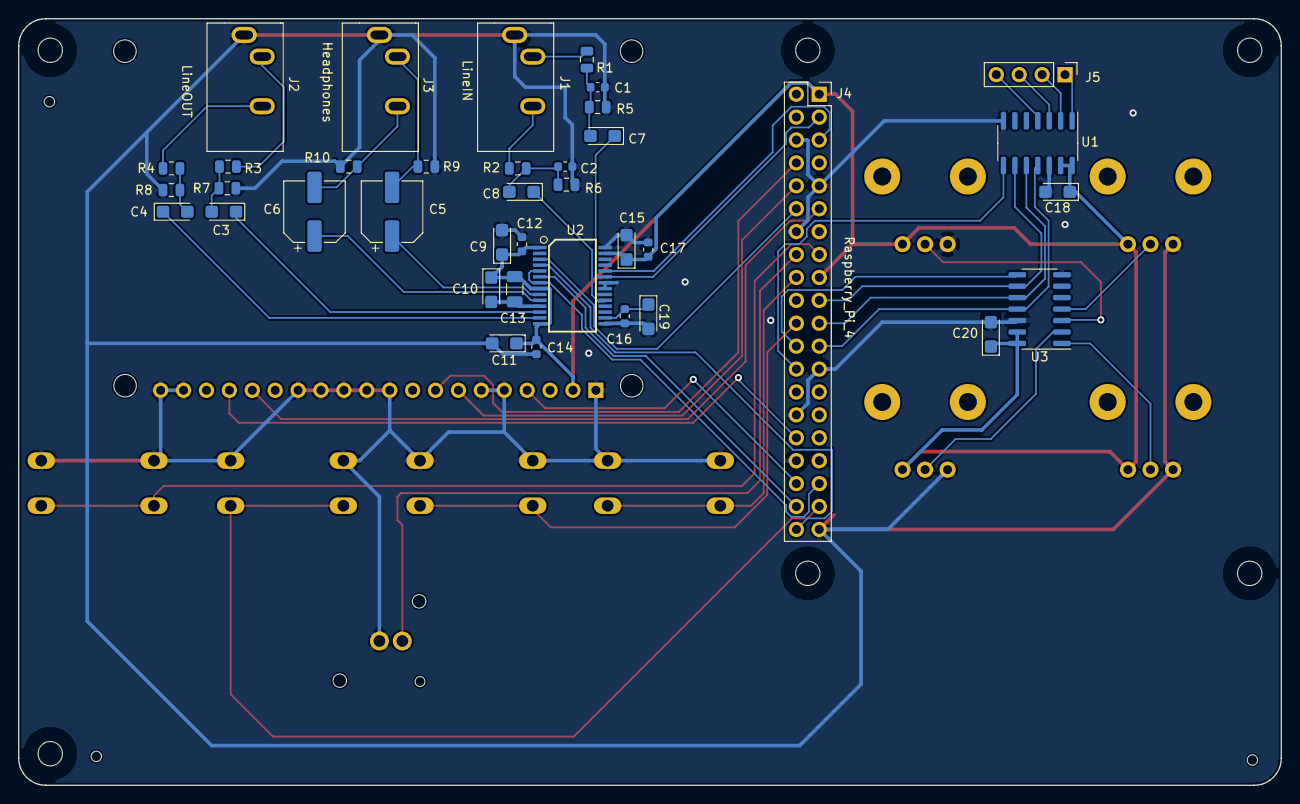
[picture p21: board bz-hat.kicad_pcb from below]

Board: 2 copper layers, 140.0 x 85.0 mm, 48 parts (38 on the bottom side), 49 nets.

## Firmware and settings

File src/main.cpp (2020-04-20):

/** @file main.cpp
 *
 *  @brief implementation file of BZZZBZ main
 *
 * @author Marcell Illyes (marcellillyes), Peter Nagy (deetrone), Davide Rovelli (daviderovell0)
 *
 */

// Standard libraries
#include <iostream>
#include <fstream>
#include <stdio.h>
#include <stdlib.h>
#include <math.h>
// Use glew.h or gl.h but first declares all prototypes
#include <GL/glew.h>
#include <GL/freeglut.h>

// SPI-related libraries
#include <stdint.h>
#include <unistd.h>
#include <fcntl.h>
#include <sys/ioctl.h>
#include <linux/types.h>
#include <linux/spi/spidev.h>

// Custom classes
#include "MCP3008Comm.h"
#include "AudioProcessing.h"
#include "shader_utils.h"
#include "TestLatency.h"



/***** OpenGL globals *****/
GLuint vbo_window;
GLuint program;
GLint attribute_coord3d;
GLint uniform_width;
GLint uniform_height;
GLint uniform_pA;
GLint uniform_pB;
GLint uniform_pC;
GLint uniform_fft;

struct attributes {
  GLfloat coord3d[3];
};

/***** Control interface *****/
float pot_A=0.9;
float pot_B=0.7;
float pot_C=0.6;


/***** Audio processing globals *****/

// Initalise audio processing instance with default constructor 
AudioProcessing *ap = new AudioProcessing(); 

// length of the FFT buffer is determined by the number of frames set by JACK server.
// here it is started with default settings: sr=48KHz, frames=1024, period=2, driver=alsa
const int nfft = 1024;
// audio buffer
float *audio_buffer = (float *) malloc(nfft*sizeof(float));
// lock for buffer transfer
bool audio_locked = false;
//input fft buffer
float *fft_buffer_in = new kiss_fft_scalar[nfft];
// output values to be used in the video
float *fft_frame_out = (float *) malloc((nfft/2+1)*sizeof(float));


/**
 *  Terminate the JACK client when exiting the program, to avoid errors in the 
 * following executions.
*/
void signal_handler(int sig){
	fprintf(stderr, "signal received, closing JACK client...\n");
  ap->stop();
  free(fft_frame_out);
}

/**
 * Define the audio process routine callback.
 * Get the lock and copy the buffer over. Don't do anything with the output
 * as it is already bypassed by the chip
 */
class ReadBuffer : public AudioProcessingCallback {    
    virtual void process(float* in_buffer, float* out_buffer) {
      // don't wait for the FFT buffer copy, keep reading audio
      if(!audio_locked){
        audio_locked = true;
        memcpy(audio_buffer,in_buffer, nfft*sizeof(float));
        audio_locked = false;
      }
    }
};

/**
 * SPI sample callback class
 * Processing the output samples coming from the MCP3008 ADC 
 **/
class MCP3008pollChannelsCallback : public MCP3008callback {
	virtual void hasSample(int value, int channel) {
		switch (channel)
    {
    case 4:
      pot_A = value/1024.0;
      break;
    
    case 5:
      pot_B = value/1024.0;
      break;
    
    default:
      break;
    };
	}
};


// OPENGL FUNCTIONS
/**
* \brief Initialise all resources for OpenGL: Vertex Buffer Object, 
* create shaders and attach to program object and bind attributes and uniforms
**/
int init_resources()
{ 
  //vertices, z=0
  struct attributes window_attributes[] = {
    {{ -1.0,  1.0, 0.0}},
    {{-1.0, -1.0, 0.0}},
    {{ 1.0, -1.0, 0.0}},
    {{ 1.0, 1.0, 0.0}},
    {{ -1.0, 1.0, 0.0}}
  };
  
  glGenBuffers(1, &vbo_window);
  glBindBuffer(GL_ARRAY_BUFFER, vbo_window);
  glBufferData(GL_ARRAY_BUFFER, sizeof(window_attributes), window_attributes, GL_STATIC_DRAW);

  GLuint vs, fs;
  if ((vs = create_shader("shaders/vertex.glsl", GL_VERTEX_SHADER))   == 0) return 0;
  if ((fs = create_shader("shaders/cells.glsl", GL_FRAGMENT_SHADER)) == 0) return 0; //must be set manually for correct shader
  
  program = create_program(program, vs, fs);

  const char* attribute_name = "coord3d";
  attribute_coord3d = glGetAttribLocation(program, attribute_name);
  if (attribute_coord3d == -1) {
    fprintf(stderr, "Could not bind attribute %s\n", attribute_name);
    return 0;
  }
  //if multiple program we can choose which uniforms are bound where
  const char* uniform_name;
  uniform_name = "H";
  uniform_height = glGetUniformLocation(program, uniform_name);
  if (uniform_height == -1) {
    fprintf(stderr, "Could not bind uniform_height %s\n", uniform_name);
    return 0;
  }
  uniform_name = "W";
  uniform_width = glGetUniformLocation(program, uniform_name);
  if (uniform_width == -1) {
    fprintf(stderr, "Could not bind uniform_width %s\n", uniform_name);
    return 0;
  }

  uniform_name = "fft";
  uniform_fft = glGetUniformLocation(program, uniform_name);
  if (uniform_fft == -1) {
    fprintf(stderr, "Could not bind uniform_width %s\n", uniform_name);
    return 0;
  }
  uniform_name = "A";
  uniform_pA = glGetUniformLocation(program, uniform_name);
  if (uniform_pA == -1) {
    fprintf(stderr, "Could not bind uniform_pA %s\n", uniform_name);
    return 0;
  }
  uniform_name = "B";
  uniform_pB = glGetUniformLocation(program, uniform_name);
  if (uniform_pB == -1) {
    fprintf(stderr, "Could not bind uniform_pB %s\n", uniform_name);
    return 0;
  }
  uniform_name = "C";
  uniform_pC = glGetUniformLocation(program, uniform_name);
  if (uniform_pC == -1) {
    fprintf(stderr, "Could not bind uniform_pC %s\n", uniform_name);
    return 0;
  }
  return 1;
}

void onIdle() {
/**
*Idling function of OpenGL renderer. Wait for audio buffer to fill then copy buffer and run fft. Update uniforms such as screen size, controls, fft. Callback to display function
**/
  
  float window_width=glutGet(GLUT_WINDOW_HEIGHT); //fix viewport for correct division and no stretching
  float window_height=glutGet(GLUT_WINDOW_HEIGHT);
  
  while(audio_locked); // wait audio processing callback to finish
  audio_locked = true;
  memcpy(fft_buffer_in,audio_buffer, nfft*sizeof(float));
  audio_locked = false;
  
  // compute fft
  ap->runFFT(fft_buffer_in,fft_frame_out,nfft);
 
  // Pass values to shader
  //when switching modes change program accordingly
  glUseProgram(program);
  glUniform1f(uniform_width, window_width);
  glUniform1f(uniform_height, window_height);
  glUniform1f(uniform_pA, pot_A);
  glUniform1f(uniform_pB, pot_B);
  glUniform1f(uniform_pC, pot_C);
  glUniform1fv(uniform_fft, nfft/2+1,fft_frame_out);
  glutPostRedisplay();
}

void onDisplay()
{
/** 
* Display function of OpenGL renderer. Select program, and draw arrays from VBO. Swap between front and back buffer.
**/

  glClearColor(1.0, 1.0, 1.0, 1.0); // empty == white
  glClear(GL_COLOR_BUFFER_BIT);
  glUseProgram(program); //must be changed from modes
  //same for all programs, as attribute_coord3d is always bound
  glEnableVertexAttribArray(attribute_coord3d);
  glBindBuffer(GL_ARRAY_BUFFER, vbo_window);
  glVertexAttribPointer(
    attribute_coord3d,   // attribute
    3,                   // number of elements per vertex, here (x,y,z)
    GL_FLOAT,            // the type of each element
    GL_FALSE,            // take our values as-is
    0,                  //every element appears...
    0                    // offset of first element
  );

  // Push each element in buffer_vertices to the vertex shader, create rectangle
  glDrawArrays(GL_TRIANGLES, 0, 3);
  glDrawArrays(GL_TRIANGLES, 2, 3);
  glDisableVertexAttribArray(attribute_coord3d);
  glutSwapBuffers();
 

}

void free_resources() 
{   
/**
* Delete program object(s) and VBO to free up memory.
**/
  glDeleteProgram(program);
  glDeleteBuffers(1, &vbo_window);
}

int main(int argc, char *argv[]){
/**
* Main loop. Initialises classes, register callbacks. Starts threads and video rendering. Free resources on stop.
**/
    
    // Set the exit routine: Keep running until exit signal (ctrl+C) received.
    signal(SIGQUIT, signal_handler);
	signal(SIGTERM, signal_handler);
	signal(SIGHUP, signal_handler);
	signal(SIGINT, signal_handler);

    //Instantiate SPI related classes and start readouts
    MCP3008Comm* m = new MCP3008Comm();
    MCP3008pollChannelsCallback poll_cb;
    m->setCallback(&poll_cb);
    m->start();

    ReadBuffer cb;
    ap->setCallback(&cb);

    ap->start();

    // opengl
    //init context
    glutInit(&argc, argv);
    glutInitContextVersion(2,0);
    glutInitDisplayMode(GLUT_RGBA|GLUT_ALPHA|GLUT_DOUBLE|GLUT_DEPTH);
    glutInitWindowSize(glutGet(GLUT_SCREEN_WIDTH), glutGet(GLUT_SCREEN_HEIGHT));
    glutCreateWindow("BZZZBZ");
    //error handling, important for non-Pi implementations
    GLenum glew_status = glewInit();
    if (glew_status != GLEW_OK) {
        fprintf(stderr, "Error: %s\n", glewGetErrorString(glew_status));
        return 1;
    } 
    if (!GLEW_VERSION_2_0) {
        fprintf(stderr, "Error: your graphic card does not support OpenGL 2.0\n");
        return 1;
    }
    //main loop if init_resources returns 1
    if (init_resources()) {
      
        glutDisplayFunc(onDisplay);
        glutIdleFunc(onIdle);
        glEnable(GL_BLEND);
        glBlendFunc(GL_SRC_ALPHA, GL_ONE_MINUS_SRC_ALPHA);
        glutMainLoop();
    }

    // Terminate threads, free resources
    m->stop();
    delete m;
    ap->stop();
    free(audio_buffer);
    free(fft_buffer_in);
    free(fft_frame_out);
    free_resources();
    return 0;
}

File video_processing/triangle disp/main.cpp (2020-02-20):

/*This source code copyrighted by Lazy Foo' Productions (2004-2013)
and may not be redistributed without written permission.*/
//Version: 001

#include "LUtil.h"

void runMainLoop( int val ); //this actually comes later...
/*
Pre Condition:
 -Initialized freeGLUT
Post Condition:
 -Calls the main loop functions and sets itself to be called back in 1000 / SCREEN_FPS milliseconds
Side Effects:
 -Sets glutTimerFunc
*/

int main( int argc, char* args[] )
{
	//Initialize FreeGLUT
	glutInit( &argc, args );

	//Create OpenGL 2.1 context
	glutInitContextVersion( 2, 1 ); //so that not modern OpenGL etc

	//Create Double Buffered Window
	glutInitDisplayMode( GLUT_DOUBLE ); //there are a few arguments available...
	glutInitWindowSize( SCREEN_WIDTH, SCREEN_HEIGHT ); //gets from header
	glutCreateWindow( "First test" );

	//Do post window/context creation initialization
	if( !initGL() )
	{
		printf( "Unable to initialize graphics library!\n" );
		return 1;
	}

	//Set rendering function
	glutDisplayFunc( render ); //not entirely sure, "render" here creates the triangle and swaps front/back

	//Set main loop
	glutTimerFunc( 1000 / SCREEN_FPS, runMainLoop, 0 ); //at least every 1000/FPS, runMainLoop is called

	//Start GLUT main loop
	glutMainLoop();

	return 0;
}

void runMainLoop( int val )
{
    //Frame logic
    update();
    render();

    //Run frame one more time
    glutTimerFunc( 1000 / SCREEN_FPS, runMainLoop, val );
}

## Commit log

2020-03-02 Breakout PCB v1
    [wm8731-breakout.kicad_pcb, wm8731-breakout.sch]
2020-03-24 Added schematic PDF
2020-03-28 Sample audio data + simple py plotter
2020-03-30 Pi sample data
2020-03-31 kiss_fft for sample data init
2020-03-31 Simple potentiometer program
    SPI classes to read in the potentiometer values
2020-04-01 kissFFT test and plot on sample data
2020-04-03 Draft AudioProcessing class (BUG)
    [main.cpp]
2020-04-04 Bug fixed. Working incoming audio within cpp class
    [main.cpp]
2020-04-04 rolling FFT with audio. NON-threaded
2020-04-09 Included control for potentiometers over SPI
2020-04-11 Made the bass bin (0,750Hz] of the FFT_frame a dynamic variable in OpenGL
2020-04-14 increased buffer size to (try) to avoid xrun
    [main.cpp]
2020-04-14 Fixed FFT bug. Working eq on laptop with nfft 1024
    [main.cpp]
2020-04-15 Improved Makefile for video_processing sample shader
2020-04-16 Dependencies script for raspberry pi
2020-04-18 Added hardware files for control + relative medias
    [mcp3008_breakout.sch]
2020-04-18 created examples for to demo opengl, spi and audio (fft)
2020-04-19 Added the TestLatency class and initialized in main Can be used for measuring the time delay between acquiring audio data and swapping buffers upon render in GLUT with an oscilloscope
    [main.cpp]
2020-04-20 update main.cpp and cells.glsl to fixed values, disabled ap and m
    [MCP3008Comm.cpp, main.cpp, spi_test.cpp]
2021-02-22 board v2 init and folder restructure
    [bz-hat.kicad_pcb, bz-hat.sch, components.csv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]
2021-02-22 KiCAD - raspberrypi 4 symbol and MCP3004s added
    [bz-hat.sch, components.csv]
2021-02-24 v2 schematic full draft
    [bz-hat.sch]
2021-02-27 Fixed ERC. Full v2 sombrero schematic
    [bz-hat.sch]
2021-03-02 big button (PB300) footprint
    [bz-hat.sch, components.csv]
2021-03-06 Fixed footprints and added 3d models
    [B3F-4050--3DModel-STEP-273799.STEP, CUI_DEVICES_SJ1-3533NG.step, PB300STQ--3DModel-STEP-1.STEP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]
2021-03-07 v2 board, mounting holes + draft components placement
    [960240-6202-AR.STEP, bz-hat.sch]
2021-03-09 v2 board placement and routing finished
    [bz-hat.kicad_pcb, bz-hat.sch]
2021-03-25 logo + gerbers + JLPCB refs. to symbols
    [bz-hat-B_Cu.gbr, bz-hat-B_Mask.gbr, bz-hat-B_SilkS.gbr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]
2021-03-26 added BOM and pick and place file
    [bz-hat.csv, bz-hat.kicad_pcb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]
2021-03-30 Fixed C19 wrong footprint
    [bz-hat.kicad_pcb, bz-hat.sch]
2021-03-30 Updated gerbers + BOM + centroid files for JLCPCB
    [BOM.csv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]
2021-04-11 Added interactive BOM with manufacturer, distributor, price fields
    [BOM_jlcpcb.csv, bz-hat.kicad_pcb, bz-hat.sch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]
2021-04-21 Full BOM with pricing uploaded, male header and SD missing
    [BOM_full.xls]
2021-05-09 MCP3004 implementation + updated spi test for brd v2
    [bz-hat.kicad_pcb]
2021-05-25 added last components in BOM for prices reference
    [BOM_full.xls, components.csv]
2021-05-25 pictures of board v2 assembled and mounted
